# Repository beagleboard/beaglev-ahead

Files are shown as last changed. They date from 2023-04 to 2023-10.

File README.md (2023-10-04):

# BeagleV-Ahead

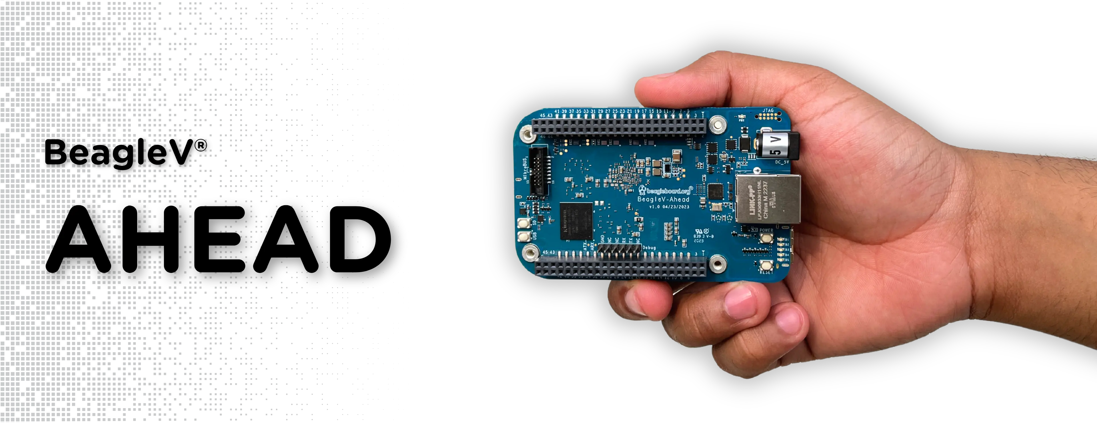
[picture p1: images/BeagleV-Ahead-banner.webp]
BeagleV Ahead banner


## Certified open source

<a href="https://certification.oshwa.org/us002535.html">
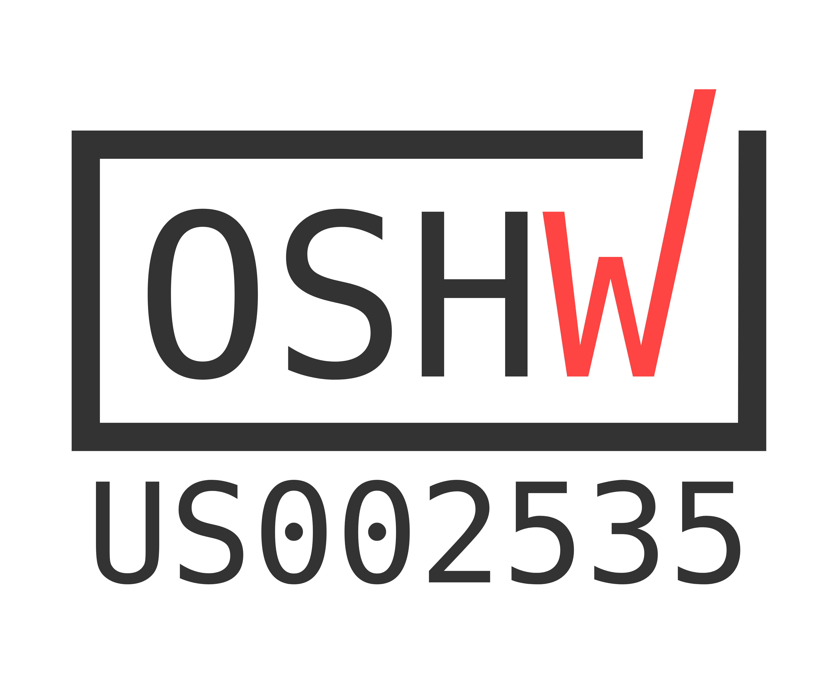
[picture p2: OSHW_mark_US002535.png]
   
</a>

## Links

* Terms and conditions: https://docs.beagleboard.org/latest/boards/terms-and-conditions.html
* Documentation: https://docs.beagleboard.org/latest/boards/beaglev/ahead
* Design: https://git.beagleboard.org/beaglev-ahead/beaglev-ahead
* Support: https://forum.beagleboard.org/tags/c/beaglev/15/ahead
* Repair: https://www.beagleboard.org/rma
* Purchase: https://beaglev-ahead.org

## Features

* T-Head TH1520 AI system-on-chip processor
   * Quad-core XuanTie C910 open-source RTL RISC-V (RV64GCV ISA) CPU @ 2GHz
     * 3 issue, 8 instruction, 9-12 stage pipeline
     * In-order fetch, out-of-order launch, out-of-order completion and in-order retirement
     * 64KB I-cache, 64KB D-cache per core
   * AI NPU with 4TOPS INT8 @ 1GHz
     * Support for TensorFlow, ONNX, Caffe
     * Feature extraction accelerator
   * Image signal processor
   * H.264/H.265/JPEG video encoder and decoder
   * 2D accelerator
   * 3D Vulkan/OpenCL/OpenGLES accelerator (IMG?)
   * C906-based (RV64IMA\[FD]C\[V] ISA) audio processor subsystem
* 4GB LPDDR4
* 16GB eMMC
* New Beagle form-factor open-source development board
   * ~2xSuperSpeed-USB type-A host (stacked)~
   * SuperSpeed USB type-C dual-role with power input (no power output)
   * Consider adding USB-to-serial/JTAG for the type-C device and move USB to host-only
   * Gigabit Ethernet with speed/connection indicators
   * HDMI type-A connector
   * TBD SDIO WiFi
   * uSD card cage
   * 2xCSI ribbon cable connectors
   * 1xDSI ribbon cable connector
   * 2x46-pin expansion headers with 4-pin HS-USB extension
   * 2x8-pin "mikroBus shuttle" ribbon-cable connector for audio and sensors
   * 3-pin TTL-level debug UART connector
   * Fan power connector (fan is optional)
   * 6x LEDs (1 power, 5 programmable)
   * 3x push-buttons (power, reset, boot/user)
   * 5V barrel jack
* BeagleBoard.org Debian Linux image
   * Tracking mainline u-boot/kernel with T-Head patches as needed
   * Package feeds for custom binaries for TensorFlow Lite, etc.
   * Familiar and flexible graphical user interface environment
   * Self-hosted Visual Studio Code IDE via web-browser
   * USB-based virtual network for "single-cable development"

# Requirements to begin
* Documentation needs to *start*
   * Reference schematic and PCB source files
      * Reference for DDR
      * Reference for PMIC and power design
   * Additional SoC details (Chinese language is good) - pointers to licensed IP is fine
      * Power consumption
   * Clear legal path to usage
      * Verify the IP in the SoC is licensed for use
      * Verify the IP *user* documentation can be public
      * Signed 3P agreement
   * Supplier part commitment
      * 10k parts for launch
      * ~~50k units per year~~
      * ~~fixed price and availability 5 years as long as 10k units per year~~
    * SDK source required to test board
      * Review Linux device tree
* Documentation needs to *launch*
   * Additional SoC details (Chinese language is good) - pointers to licensed IP is fine
      * Overview of SoC Memory Map
      * Boot process
      * Clocking and reset
      * Interrupts map or List
      * PLIC (Platform Level Interrupt Controller)
      * CLINT (Core-Local Interruptor)
      * L2 Cache Controller
      * DMA Controller
      * DDR interface
      * UART peripheral (including register map)
      * PWM peripheral (including register map)
      * I2C controller (including register map)
      * SPI controller (including register map)
      * GPIO controller (including register map)
      * Gigabit Ethernet MAC (including register map)
      * USB controller (including register map)
   * SDK source
      * Open source Linux kernel with reasonable SoC entitlement (or register-level detailed IP documentation)
      * V4L2 driver for video encoder/decoder
      * IMG 3D open source Mesa/Vulkan driver
      * libcamera and V4L2 driver for ISP and CSI video interace for common sensors (IMX219-based Pi camera)
      * DRM driver for the 2D image accelerator, display processing unit and DSI video interface
      * ALSA driver for audio interface

## DVT v0.2 testing

1. [Flash latest Ubuntu image](flashing.md)
2. [UART debug port access](debug.md)
3. [WiFi connection](WiFi.md)
4. [GPIO testing](GPIO.md)
5. [Bluetooth testing](Bluetooth.md)

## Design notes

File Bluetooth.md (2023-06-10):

# Setup Bluetooth

To connect to wifi we will be using `wpa_cli` tool, first we need to set the credentials for the wifi and then we will initialize the connection by reconfiguiring the wlan0 interface to use new credentials.
we use `brcm_patchram_plus` tool to setup bluetooth, first we need to trigger reset pin, then upload bluetooth fw.

```shell
#trigger reset pin
gpioset gpiochip2 28=0
gpioset gpiochip2 28=1

#upload fw
brcm_patchram_plus --enable_hci --no2bytes --tosleep 200000 --baudrate 3000000 --patchram /lib/firmware/BCM43013A0_001.001.006.1073.1102.hcd /dev/ttyS4 &
```

# Setup Bluetooth (with Debug)
```
#upload fw
brcm_patchram_plus -d --enable_hci --no2bytes --tosleep 200000 --baudrate 3000000 --patchram /lib/firmware/BCM43013A0_001.001.006.1073.1102.hcd /dev/ttyS4 &
```

## Check bluetooth interface

```
root@BeagleV:~# hciconfig 
hci0:	Type: Primary  Bus: UART
	BD Address: B8:13:32:EC:59:8B  ACL MTU: 1021:8  SCO MTU: 64:1
	DOWN 
	RX bytes:733 acl:0 sco:0 events:42 errors:0
	TX bytes:464 acl:0 sco:0 commands:42 errors:0
```

## Using bluetoothctl tool 

```
root@BeagleV:~# bluetoothctl 
Agent registered
[CHG] Controller B8:13:32:EC:59:8B Pairable: yes
[bluetooth]# scan on
Discovery started
[CHG] Controller B8:13:32:EC:59:8B Discovering: yes
[NEW] Device 40:97:1C:DF:8B:BD 40-97-1C-DF-8B-BD
[NEW] Device 43:07:E7:3F:85:84 43-07-E7-3F-85-84
[CHG] Device 43:07:E7:3F:85:84 RSSI: -91
[bluetooth]# quit

```

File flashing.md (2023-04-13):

# Flashing Ubuntu image

To start flashing the board download the latest image from the link below:

https://git.beagleboard.org/beaglev-ahead/xuantie-ubuntu/-/jobs

```
NOTE: New jobs are being executed regularly and it's recommended to download the most recent Ubuntu image by clicking the buttom marked in the image below.
```

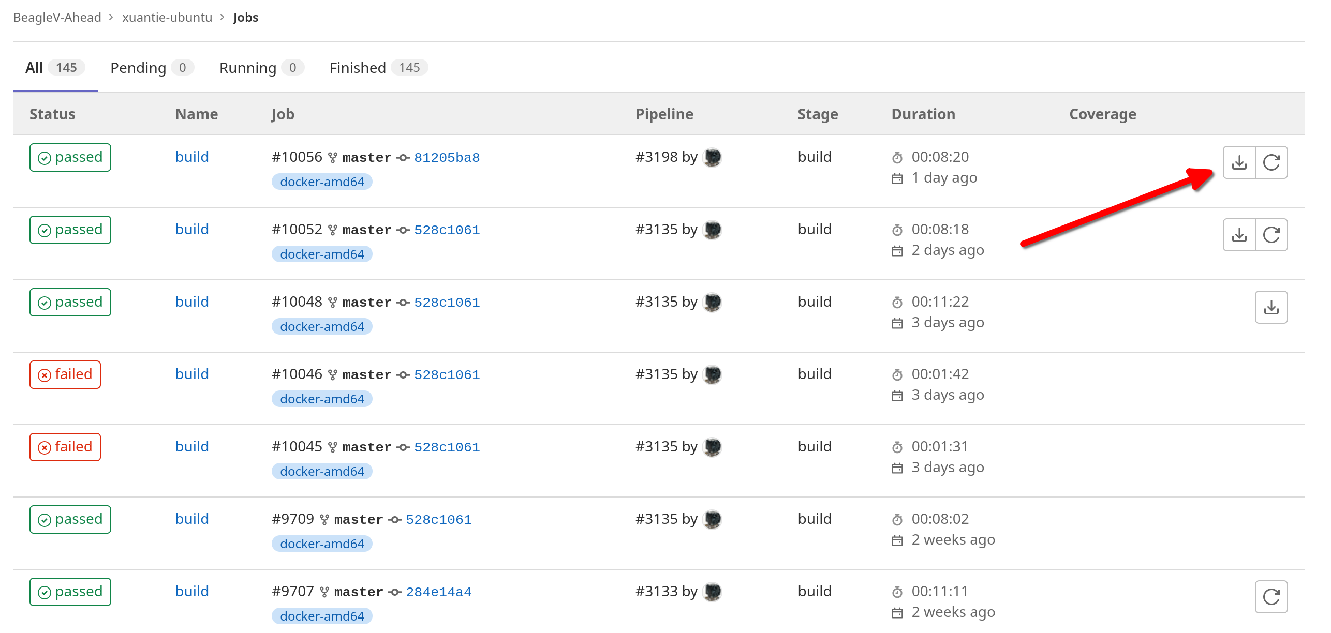
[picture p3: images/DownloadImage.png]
Download recent image


## Extract files
After downloading the `xuantie-ubuntu-<job-ID>.zip` using the link above, extract the zip file. The zip file has four files shown below:

    [lorforlinux@fedora deploy] $ ls 
        boot.ext4  fastboot_emmc.sh  root.ext4  u-boot-with-spl.bin

## Flash Board over USB

Press the USB button near SD card holder and then connect the board to PC with your custom USB3 (blue) cable provided with the BeagleV Ahead board. Now, Execute the command below, provide your password and the flashing will start.

    [lorforlinux@fedora deploy] $ sudo ./fastboot_emmc.sh 
    [sudo] password for lorforlinux:

```
NOTE: you may require to install adb & android-fastboot onto your system if not already available.
```

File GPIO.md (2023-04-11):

# GPIO

BeagleV Ahead has cape header pins similar to BeagleBone Black. You can check the documentation page below to know the pin connection to TH1520 SoC:

https://beaglev-ahead.beagleboard.io/docs/latest/boards/beaglev/ahead/connectros.html

To test the GPIO functionality of the pins you can follow steps below:

## Clone BeagleBoard-DeviceTrees

1. Access the shell with the help of [debug.md](debug.md)
2. Connect to WiFi usig [WiFi.md](WiFi.md)
3. Change directory to home using like below:

    ```
    beagle@BeagleV:~$ cd
    ```

4. Clone the repo using command below:

    ```
    beagle@BeagleV:~$ git clone https://git.beagleboard.org/beaglev-ahead/BeagleBoard-DeviceTrees.git
    ```

    Provide your credentials and the wait for cloning to complete.

## Teset gpio-leds with BONE-LED

Follow the steps below to test,

1. change the directory to home,

        ```
        beagle@BeagleV:~$ cd
        ```

2. If not already cloned clone the BeagleBoard-DeviceTrees repo,

    ```
    beagle@BeagleV:~$ git clone https://git.beagleboard.org/beaglev-ahead/BeagleBoard-DeviceTrees.git
    ```

3. Change directory to the repo,

    ```
    beagle@BeagleV:~$ cd BeagleBoard-DeviceTrees/
    ```

4. This step is not required for the first run but handy for further debugging,

    ```
    beagle@BeagleV:~$ make clean
    ```

5. make all the devicetree files and overlays for riscv

    ```
    beagle@BeagleV:~$ make all_riscv
    ```

6. Until uboot overlays support is functional you can use this command to update the base device tree file to include our overlay,

    ```
    beagle@BeagleV:~$ fdtoverlay \
    -i src/riscv/light-beagle.dtb \
    -o src/riscv/light-beagle.dtb \
    src/riscv/overlays/BONE-LED_P8_03.dtbo
    ```

7. Install all the files to your board,

    ```
    beagle@BeagleV:~$ sudo make install_riscv
    ```

8. Reboot your board,

    ```
    beagle@BeagleV:~$ sudo reboot
    ```

9. You should see LED blinking if connected to `P8_03`.

## Testing other pins

The overlay can be updated for other header pins and same steps can be used to test the pins as well. 

You'll have to change [this](https://git.beagleboard.org/beaglev-ahead/BeagleBoard-DeviceTrees/-/blob/v5.10.x-ti-unified/src/riscv/overlays/BONE-LED_P8_03.dts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) line according to the pin you want to use.

```
NOTE: It's okay if you don't change anything else like file name and other parts of the overlay to test other pins, you just have to change the reference according to the pin you want to test.
```

For `P8_03` the reference used is `bone_led_P8_03` for other pin like `P8_04` you need to change it to `bone_led_P8_04`. For example, testing `P8_22` will require you to make the change below:

```
&bone_led_P8_22 {
    status = "okay";
    // access: sys/class/leds/led_P8_22
    label = "led_P8_22";
    linux,default-trigger = "heartbeat";
    default-state = "on";
};
```

please note that this is only the portion of the code we need to edit, everything else can be exactly the same unless you really see the need to change it for yourself because it will not affect the testing procedure of the pin.

## Capes

Overlays for LOAD cape and Relay cape are also available to test under overlays folder,

https://git.beagleboard.org/beaglev-ahead/BeagleBoard-DeviceTrees/-/tree/v5.10.x-ti-unified/src/riscv/overlays

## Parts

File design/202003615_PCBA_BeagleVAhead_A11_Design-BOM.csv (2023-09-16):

标识 | 品牌 | MPN码 | 规格 | 插件位置 | 底数 | 数量 | 单位 | 承样状态 | 创建时间
202003615, PCBA; BeagleV-Ahead, A.11 (Design) |  |  |  |  |  |  |  |  | 2022/06/15 10:41 CST
301010000, SMD RES 0R-5%-1/16W;0402, A.2 (Design) | YAGEO | RC0402JR-070RL |  | R1 R6 R103 R124 R125 R126 R127 R128 R130 R200 R201 R202 R228 R229 R230 R233 R234 R242 R243 R486 R487 R651 R801 R802 R803 R804 R806 R807 R809 | 1 | 29 | PCS | 无需承样 | 2015/10/31 16:34 CST
301010048, SMD RES 30K-1%-1/16W;0402, A.1 (Design) | YAGEO | RC0402FR-0730KL |  | R116 R131 | 1 | 2 | PCS | 无需承样 | 2015/10/31 16:03 CST
301010081, SMD RES 200K-1%-1/16W;0402, A.1 (Design) | YAGEO | RC0402FR-07200KL |  | R136 R808 | 1 | 2 | PCS | 无需承样 | 2015/10/31 15:50 CST
301010359, SMD RES 0R-5%-1/8W;0805, A.1 (Design) | YAGEO | RC0805JR-070RL |  | R13 | 1 | 1 | PCS | 无需承样 | 2015/10/31 15:55 CST
301010410, SMD RES 1M-1%-1/4W;1206, A.1 (Design) | YAGEO | RC1206FR-071ML |  | R112 | 1 | 1 | PCS | 无需承样 | 2015/10/31 15:55 CST
301010442, SMD RES 100R-1%-1/16W;0402, A.1 (Design) | YAGEO | RC0402FR-07100RL |  | R7 | 1 | 1 | PCS | 无需承样 | 2015/10/31 15:47 CST
301010523, SMD RES 1K-±1%-1/20W;0201, A.1 (Design) | YAGEO | RC0201FR-071KL |  | R109 R110 R121 R123 R144 R185 R186 R187 R188 R189 R190 R191 R192 R193 R194 R195 R225 R232 | 1 | 18 | PCS | 无需承样 | 2015/10/31 16:25 CST
301010525, SMD RES 0R-±1%-1/20W;0201, A.1 (Design) | YAGEO | RC0201FR-070RL |  | R49 R52 R56 R61 R62 R74 R78 R106 R108 R156 R235 R236 R237 R238 R239 R240 R241 | 1 | 17 | PCS | 无需承样 | 2015/10/31 16:34 CST
301010526, SMD RES 10K-±1%-1/20W;0201, A.1 (Design) | YAGEO | RC0201FR-0710KL |  | R10 R15 R21 R40 R87 R91 R92 R93 R113 R117 R118 R129 R132 R133 R134 R137 R139 R141 R145 R146 R147 R148 R149 R158 R160 R162 R164 R166 R168 R169 R170 R171 R180 R203 R204 R205 R207 R209 R211 R213 R215 R217 R219 R221 R223 | 1 | 45 | PCS | 无需承样 | 2015/10/31 16:34 CST
301010671, SMD RES 2.7K-1%-1/16W;0402, A.2 (Design) | YAGEO | RC0402FR-072K7L |  | R143 | 1 | 1 | PCS | 未承样 | 2015/10/31 15:54 CST
301010675, SMD RES;33R-5%-1/20W;0201, A.1 (Design) | YAGEO | RC0201JR-0733RL |  | R5 R37 R53 R54 R55 R67 R68 R69 R70 R71 R72 R73 R75 R76 R77 R79 R83 R84 R85 R86 R88 R90 R150 | 1 | 23 | PCS | 未承样 | 2015/10/31 15:56 CST
301010676, SMD RES 1M-5%-1/20W;0201, A.3 (Design) | YAGEO | RC0201JR-071ML |  | R135 R138 R140 R142 R157 R159 R161 R163 R165 R167 R199 R206 R208 R210 R212 R214 R216 R218 R220 R222 R224 R226 | 1 | 22 | PCS | 无需承样 | 2015/10/31 16:02 CST
301010677, SMD RES;4.7K-5%-1/20W;0201, A.1 (Design) | YAGEO | RC0201JR-074K7L |  | R19 R22 R23 R28 R29 R30 R41 R42 R43 R45 R46 R47 R48 R57 R58 R59 R60 R63 R64 R65 R66 | 1 | 21 | PCS | 未承样 | 2015/10/31 16:02 CST
301010746, SMD RES 2.2K-1%-1/16W;0402, A.1 (Design) | YAGEO | RC0402FR-072K2L |  | R155 | 1 | 1 | PCS | 未承样 | 2015/10/31 16:54 CST
301010765, SMD RES 100K-±1%-1/20W;0201, A.1 (Design) | YAGEO | RC0201FR-07100KL |  | R44 R115 R119 R122 R172 R174 R181 R183 R184 R227 R673 R800 R810 R811 R813 R814 R815 R816 | 1 | 18 | PCS | 无需承样 | 2015/10/31 15:51 CST
301010817, SMD RES 1.62K-1%-1/20W;0201, A.3 (Design) | YAGEO | RC0201FR-071K62L |  | R94 R105 R114 R120 R755 | 1 | 5 | PCS | 无需承样 | 2015/10/31 17:01 CST
301010856, SMD RES 2.49K-1%-1/16W;0402, A.2 (Design) | YAGEO | RC0402FR-072K49L |  | R104 | 1 | 1 | PCS | 无需承样 | 2015/11/09 14:39 CST
301010860, SMD RES 124K-1%-1/16W;0402, A.2 (Design) | YAGEO | RC0402FR-07124KL |  | R102 | 1 | 1 | PCS | 无需承样 | 2015/11/09 14:42 CST
301011226, SMD RES 560K-1%-1/16W;0402, A.1 (Design) | YAGEO | RC0402FR-07560KL |  | R101 | 1 | 1 | PCS | 无需承样 | 2016/03/01 16:17 CST
301011318, SMD RES 240R-1%-1/20W;0201, A.1 (Design) | YAGEO | RC0201FR-07240RL |  | R3 R4 R8 R9 | 1 | 4 | PCS | 无需承样 | 2016/03/31 18:53 CST
301011323, SMD RES 120R-1%-1/20W;0201, A.1 (Design) | YAGEO | RC0201FR-07120RL |  | R11 R16 R35 | 1 | 3 | PCS | 无需承样 | 2016/03/31 19:01 CST
301011530, SMD RES 27R-1%-1/20W;0201, A.1 (Design) | YAGEO | RC0201FR-0727RL |  | R80 R81 R82 R89 R95 R96 | 1 | 6 | PCS | 无需承样 | 2016/08/12 14:10 CST
301012651, SMD RES 47K-1%-1/20W;0201, A.2 (Design) | Yageo | RC0201FR-0747KL |  | R20 R151 R152 R153 R154 | 1 | 5 | PCS | 无需承样 | 2019/05/10 11:09 CST
301013351, SMD RES 200R-1%-1/20W;0201, A.1 (Design) | YAGEO | RC0201FR-07200RL |  | R25 R751 R752 R753 R754 | 1 | 5 | PCS | 无需承样 | 2022/03/23 11:34 CST
302010002, SMD CAP Ceramic 47nF-25V-10%-X7R;0402, A.2 (Design) | YAGEO | CC0402KRX7R8BB473 |  | C643 | 1 | 1 | PCS | 无需承样 | 2015/10/31 16:48 CST
302010012, SMD CAP Ceramic 100pF-50V-5%-NPO;0402, A.2 (Design) | YAGEO | CC0402JRNPO9BN101 |  | C117 C121 | 1 | 2 | PCS | 无需承样 | 2015/10/31 15:45 CST
302010013, SMD CAP Ceramic 220pF-50V-5%-NPO;0402, A.2 (Design) | YAGEO | CC0402JRNPO9BN221 |  | C118 C120 | 1 | 2 | PCS | 无需承样 | 2015/10/31 15:45 CST
302010019, SMD CAP Ceramic 4.7uF-6.3V-20%-X5R;0402, A.2 (Design) | YAGEO | CC0402MRX5R5BB475 |  | C1 C2 C3 C5 C11 C13 C47 C54 C60 | 1 | 9 | PCS | 无需承样 | 2015/10/31 15:48 CST
302010232, SMD CAP Ceramic 470nF-10V-10%-X5R;0402, A.1 (Design) | YAGEO | CC0402KRX5R6BB474 |  | C642 C644 | 1 | 2 | PCS | 未承样 | 2015/10/31 15:51 CST
302010270, SMD CAP Ceramic;1uF-6.3V-±20%-X5R;0201, A.1 (Design) | YAGEO | CC0201MRX5R5BB105 |  | C21 C23 C25 C45 C46 C170 C171 C172 C173 C174 C179 C180 C257 C258 C259 C260 C261 C262 C268 C269 C270 C271 C272 C273 C274 C278 C281 C282 C283 C284 C288 C289 C290 C373 C374 C375 C457 C640 C1001 C1002 C1003 C1004 C1005 C1006 C1007 C1011 C1012 C1013 C1014 C1015 C1020 C1021 C1023 C1024 C1028 C1029 C1030 C1031 C1040 C1041 C1042 C1043 C1044 C1045 C1046 C1047 C1048 C1052 C1053 C1055 C1056 C1059 C1060 C1066 C1068 C1069 C1070 C1071 C1072 C1076 C1077 C1083 C1086 C1087 C1091 C1092 C1095 C1097 C1100 C1101 C1103 C1106 C1110 C1111 C1114 C1135 C1136 C1137 C1138 C1141 C1142 C1144 C1147 C1150 | 1 | 104 | PCS | 无需承样 | 2015/10/31 15:45 CST
302010271, SMD CAP Ceramic 100nF-10V-10%-X5R;0201, A.1 (Design) | YAGEO | CC0201KRX5R6BB104 |  | C4 C6 C12 C14 C20 C22 C24 C26 C27 C28 C29 C33 C37 C38 C39 C40 C41 C42 C44 C48 C49 C50 C51 C52 C53 C55 C56 C57 C58 C59 C61 C62 C65 C66 C67 C68 C72 C74 C75 C76 C77 C78 C79 C80 C81 C82 C83 C84 C85 C86 C87 C88 C89 C90 C91 C92 C93 C94 C97 C98 C99 C100 C101 C102 C103 C104 C105 C106 C107 C108 C109 C110 C111 C112 C113 C114 C115 C116 C176 C177 C181 C275 C276 C277 C285 C286 C1008 C1009 C1026 C1027 C1051 C1057 C1062 C1073 C1074 C1084 C1093 C1098 C1109 C1140 | 1 | 100 | PCS | 无需承样 | 2015/10/31 15:46 CST
302010273, SMD CAP Ceramic;22pF-50V-5%-NPO;0201, A.1 (Design) | YAGEO | CC0201JRNPO9BN220 |  | C9 C15 C31 C32 C333 C336 C634 C639 | 1 | 8 | PCS | 无需承样 | 2015/10/31 15:47 CST
302010394, SMD CAP Ceramic 1nF-50V-5%-X7R;0402, A.1 (Design) | YAGEO | CC0402JRX7R9BB102 |  | C34 C119 C122 | 1 | 3 | PCS | 未承样 | 2015/10/31 15:52 CST
302010406, SMD CAP Ceramic 18pF-50V-5%-NPO;0201, A.1 (Design) | Murata | GRM0335C1H180JA01D |  | C16 C337 C338 | 1 | 3 | PCS | 无需承样 | 2015/10/31 16:24 CST
302010411, SMD CAP Ceramic 22uF-10V-20%-X5R;0603, A.1 (Design) | YAGEO | CC0603MRX5R6BB226 |  | C10 C123 C169 C267 C600 C603 C604 C605 C607 C609 C610 C632 C633 C1000 C1010 C1119 C1120 C1129 C1130 | 1 | 19 | PCS | 无需承样 | 2015/10/31 16:47 CST
302010739, SMD CAP Ceramic 47uF-6.3V-20%-X5R;0603, A.1 (Design) | Murata | GRM188R60J476ME15D |  | C73 C601 C602 C606 C612 C620 C628 C629 C630 C673 C687 C1037 C1038 C1039 | 1 | 14 | PCS | 无需承样 | 2016/04/11 11:39 CST
302011831, SMD CAP Ceramic 10nF-6.3V-10%-X5R;0201, A.2 (Design) | Yageo | CC0201KRX5R5BB103 |  | C458 | 1 | 1 | PCS | 无需承样 | 2019/05/09 15:14 CST
302011962, SMD CAP Ceramic 1nF-2kV-10%-X7R;1206, A.3 (Design) | YAGEO | CC1206KKX7RDBB102 |  | C30 | 1 | 1 | PCS | 无需承样 | 2019/06/12 19:09 CST
302012841, SMD CAP Ceramic;220nF-10V-10%-X5R;0201, A.2 (Design) | YAGEO | CC0201KRX5R6BB224 |  | C641 | 1 | 1 | PCS | 无需承样 | 2021/02/18 16:15 CST
302013119, SMD CAP Ceramic 1uF-4V-20%-X7T;0204, A.2 (Design) | Murata | LLL152D70G105ME01D |  | C1122 C1123 C1124 C1125 C1127 C1128 | 1 | 6 | PCS | 无需承样 | 2022/07/19 16:07 CST
302013249, SMD CAP Ceramic 1uF-10V-10%-X5R;0402, A.1 (Design) | SAMSUNG | CL05A105KP5NNNC |  | C63 C64 C70 C71 C95 C96 C638 | 1 | 7 | PCS | 无需承样 | 2023/03/29 14:09 CST
302013250, SMD CAP Ceramic 10uF-6.3V-20%-X5R;0402, A.1 (Design) | SAMSUNG | CL05A106MQ5NUNC |  | C178 C287 C1034 C1035 C1036 C1067 C1075 C1085 | 1 | 8 | PCS | 无需承样 | 2023/03/29 14:13 CST
302013252, SMD CAP Ceramic 10uF-10V-10%-X5R;0603, A.1 (Design) | SAMSUNG | CL10A106KP8NNNC |  | C8 C19 C36 C43 | 1 | 4 | PCS | 无需承样 | 2023/03/29 14:14 CST
302013264, SMD CAP Ceramic 100uF-10V-20%-X5R;1210, A.1 (Design) | SAMSUNG | CL32A107MPVNNNE |  | C69 C631 | 1 | 2 | PCS | 无需承样 | 2023/03/29 14:16 CST
302013266, SMD CAP Ceramic 2.2uF-10V-10%-X5R;0402, A.1 (Design) | SAMSUNG | CL05A225KP5NSNC |  | C608 C611 C614 C615 C616 C617 C618 C619 C622 C623 C624 C625 C626 C627 | 1 | 14 | PCS | 无需承样 | 2023/03/29 14:16 CST
303010172, SMD Innductor 0.47uH-20%;L2.0*W1.6*H1.0mm, A.1 (Design) | Sunlord | WPN201610MR47MT |  | L2 | 1 | 1 | PCS | 无需承样 | 2015/10/31 15:46 CST
303011382, SMD Inductor 1uH-20%-3.1A;L2.0*W1.6*H1.0mm, A.3 (Design) | Sunlord | WPN201610U1R0MTY01 |  | L36 L37 L38 L39 L40 L43 | 1 | 6 | PCS | 无需承样 | 2020/03/12 14:51 CST
303011790, SMD Inductor;4.7uH-20%-1.5A-2.5*2.0*1.2mm, A.2 (Design) | CODACA | CSTB252012H-4R7M |  | L1 | 1 | 1 | PCS | 无需承样 | 2022/07/19 16:14 CST
303011791, SMD Inductor 2.2uH-20%-2A;L2.0*W1.6*H1.0mm, A.2 (Design) | CODACA | CSTB201610H-2R2M |  | L3 | 1 | 1 | PCS | 无需承样 | 2022/07/19 16:17 CST
303011792, SMD Inductor;0.16uH-20%-5A-2.5*2.0*1.0mm, A.2 (Design) | Sunlord | WPN252010UR16MT |  | L41 L42 | 1 | 2 | PCS | 无需承样 | 2022/07/19 16:28 CST
303030024, SMD Ferrite Bead;120R-2A;0603, A.4 (Design) | Murata | BLM18PG121SN1D |  | FB1 FB16 | 1 | 2 | PCS | 无需承样 | 2015/10/31 16:53 CST
303030040, SMD Ferrite Bead 120R-1.3A;0402, A.2 (Design) | Murata | BLM15PD121SN1D |  | FB2 FB3 FB13 FB15 | 1 | 4 | PCS | 无需承样 | 2015/11/13 16:49 CST
303030859, SMD Ferrite Bead 600R 250mA;0201, A.2 (Design) | Murata | BLM03AX601SN1B |  | FB5 FB6 FB7 FB8 FB9 FB10 FB11 FB12 | 1 | 8 | PCS | 无需承样 | 2022/07/19 16:04 CST
304020024, SMD Diode Schottky 30V-1A;DO-214AC, A.2 (Design) | Diodes | B130L-13-F |  | D24 D28 | 1 | 2 | PCS | 未承样 | 2015/10/31 15:45 CST
304020782, SMD Diode Schottky 30V-200mA;SOD-523, A.3 (Design) | ON | RB520S30T1G |  | D3 D9 D13 D32 D35 D38 | 1 | 6 | PCS | 无需承样 | 2020/04/01 17:24 CST
304050002, SMD Diode TVS 5V-600W;DO-214AA, A.2 (Design) | ST | SMBJ5.0CA-TR |  | D22 | 1 | 1 | PCS | 未承样 | 2015/10/31 16:52 CST
304050579, SMD Diode TVS 24VWM 29.5V;SMB, A.3 (Design) | Littelfuse | SMBJ24CA |  | D25 | 1 | 1 | PCS | 无需承样 | 2018/07/11 16:16 CST
304050798, SMD TVS DIODE 3.6V-6.4V-1pF;X1SON(2), A.3 (Design) | TI | TPD1E1B04DPYR |  | D14 D15 D16 D17 D18 D26 D27 | 1 | 7 | PCS | 无需承样 | 2020/01/10 11:05 CST
304060074, SMD Diode ESD 0.05pF;0402, A.3 (Design) | SEMITEL | ESDPSA0402V05 |  | D6 D7 D8 D10 D11 D19 D20 D21 D36 D37 | 1 | 10 | PCS | 无需承样 | 2015/12/28 10:56 CST
304060294, SMD Diode Array ESD;4 Channel,6 Gbps,5.5V;USON-10, A.4 (Design) | TI | TPD4E05U06DQAR | Air=±15KV；Contact=±12KV | D1 D2 D4 D5 | 1 | 4 | PCS | 无需承样 | 2020/05/14 18:47 CST
304060395, SMD Diode Array ESD;4 Channel,0.25pF,3.6V,10Gbps;USON-10, A.2 (Design) | TI | TPD4E02B04DQAR | Air=±15KV；Contact=±12KV | D12 | 1 | 1 | PCS | 无需承样 | 2022/03/21 15:05 CST
304090043, SMD LED Clear-Green;LED-0603, C.2 (Design) | Everlight | 19-217/G7C-AN1P2/6T | (正贴) | LED6 | 1 | 1 | PCS | 无需承样 | 2015/10/31 16:52 CST
304090045, SMD LED Clear-Blue;0603, A.3 (Design) | Everlight | 19-217/BHC-ZL1M2RY/6T |  | LED1 LED2 LED3 LED4 LED5 | 1 | 5 | PCS | 无需承样 | 2015/10/31 15:45 CST
305010033, SMD Transistor NPN 50V-500mA;SOT-323, A.2 (Design) | 长电 | BC817W |  | Q11 | 1 | 1 | PCS | 已承样 | 2015/10/31 15:48 CST
305030084, SMD MOSFET P-CH 20V-2.1A;SOT-323, A.1 (Design) | 长电 | CJ2101 |  | Q4 | 1 | 1 | PCS | 未承样 | 2015/10/31 15:51 CST
305030659, SMD MOSFET N-CH 20V -630MA ；SOT-523, A.2 (Design) | Diodes | DMG1012T-7 |  | Q3 Q7 Q8 Q9 Q10 Q12 Q13 Q14 Q16 Q17 Q18 Q19 Q20 Q26 Q27 | 1 | 15 | PCS | 无需承样 | 2017/09/28 10:33 CST
305031179, SMD MOSFET P-CH 30V-12A;HSMT8, A.2 (Design) | Rohm | RQ3E120ATTB |  | Q15 Q21 Q22 | 1 | 3 | PCS | 无需承样 | 2020/05/07 11:09 CST
305050191, SMD Transistor Array 2PNP 45V-0.1A;SOT36, A.2 (Design) | Diodes Incorporated | BCM857BS-7-F |  | Q23 Q24 | 1 | 2 | PCS | 无需承样 | 2019/05/10 09:59 CST
306010138, SMD Crystal 32.768KHz-12.5pF-20ppm-2P-3.2*1.5*0.9mm, A.3 (Design) | EPSON | FC-135 32.7680KA-A3 | (指定品牌) | Y1 Y8 | 1 | 2 | PCS | 无需承样 | 2015/10/31 17:02 CST
306011192, SMD Crystal 25MHz-18pF-20ppm;4P-SMD-L3.2*W2.5*H0.8mm, A.2 (Design) | Interquip | 5YAA25000182TF40Q3 |  | Y3 | 1 | 1 | PCS | 无需承样 | 2021/04/28 14:50 CST
306011309, SMD Crystal 24MHz-12pF-20ppm-60R;4P-SMD-L3.2*W2.5*H0.8mm, A.2 (Design) | Interquip | 5YAA24000122TF60Q3 |  | Y2 | 1 | 1 | PCS | 无需承样 | 2022/07/19 16:59 CST
306011310, SMD Crystal 37.4MHz-16pF-10ppm-40R;4P-SMD-L3.2*W2.5*H0.8mm, A.2 (Design) | Interquip | 5YAA37400161TF40Q3 |  | Y4 | 1 | 1 | PCS | 无需承样 | 2022/07/19 17:01 CST
306020621, SMD Oscillator;32.768KHz-3.3V-30ppm;SMD-2520-4P-L2.5*W2.0*H0.95mm, A.2 (Design) | Interquip | 1651-L3273-BTBQYA |  | OSC1 | 1 | 1 | PCS | 无需承样 | 2020/06/01 17:10 CST
306050630, SMD Feed Through Capacitor(Filters);4.3uF-20%-DC 2.5V-2A-30mOhm;0402, A.2 (Design) | Murata | NFM15PC435R0E3D |  | C1115 C1116 C1117 C1118 C1133 C1134 | 1 | 6 | PCS | 无需承样 | 2022/07/19 15:49 CST
306050631, SMD Feed Through Capacitor(Filters);22nF-20%-DC 10V-1A-40mOhm;0402, A.2 (Design) | Murata | NFM15CC223C1A3D |  | C1151 | 1 | 1 | PCS | 无需承样 | 2022/07/19 15:54 CST
310011577, SMD IC MCU;Quad-core RISC-V 2GHz;FCCSP-921(15*15), A.2 (Design) | T-HEAD | TH1520-C0X-XXXX7 |  | U1 | 1 | 1 | PCS | 无需承样 | 2022/07/19 16:32 CST
310030161, SMD IC PMIC;DFN(2*2)-8, B.2 (Design) | ETA | ETA3410D2I-T |  | U6 | 1 | 1 | PCS | 已承样 | 2015/10/31 16:48 CST
310031388, SMD IC PMIC; IC VREF SHUNT ADJ;SOT23-3, A.3 (Design) | TI | ATL431AIDBZR |  | U10 | 1 | 1 | PCS | 无需承样 | 2018/03/09 10:55 CST
310031691, SMD IC PMIC;LDO-1.8V-600mA;SOT23-5, A.2 (Design) | Diodes | AP2112K-1.8TRG1 |  | U21 | 1 | 1 | PCS | 无需承样 | 2019/05/29 10:35 CST
310032613, SMD IC PMIC;BGA-100(8*8), A.2 (Design) | Dialog | DA9063-ABHO2(T-HEAD烧录固件) |  | U81 | 1 | 1 | PCS | 无需承样 | 2022/07/19 16:52 CST
310032614, SMD IC PMIC;DCDC Buck-ADJ 2.2-V to 5.5-V Input 10-A;24WLCSP, A.2 (Design) | Dialog | DA9121-A2V72(T-HEAD提供） |  | U83 | 1 | 1 | PCS | 无需承样 | 2022/07/19 16:56 CST
310051370, SMD IC Logic;4-Bit Bidirectional Voltage-Level Translator;DSBGA-12, A.2 (Design) | Union Semiconductor | UM3304 |  | U7 U11 U12 U13 U14 U15 U16 U18 U19 U23 U24 U25 U26 U27 U28 U30 U31 | 1 | 17 | PCS | 无需承样 | 2022/07/19 16:51 CST
310051371, SMD IC Logic;4-Bit Bidirectional Voltage-Level Translator;DSBGA-12, A.2 (Design) | Union Semiconductor | UM3204H |  | U17 U22 U29 | 1 | 3 | PCS | 无需承样 | 2022/07/19 16:54 CST
310091085, SMD IC Memory;16GB eMMC 5.1;VFBGA-153, A.2 (Design) | Kingston | EMMC16G-TB29-PZ90 |  | U3 | 1 | 1 | PCS | 无需承样 | 2020/06/01 16:06 CST
310091347, SMD IC Memory;32Kb-IIC Serial EEPROM;SOT23-5, A.2 (Design) | FMD | FT24C32A-ELRT |  | U20 | 1 | 1 | PCS | 无需承样 | 2022/03/02 14:13 CST
310091405, SMD IC Memory;LPDDR4X 2GB(16bits x 2 channels) 2133MHz 4266Mbps;WFBGA-200 (10X15), A.2 (Design) | Samsung | K4U6E3S4AA-MGCR |  | UD1 UD2 | 1 | 2 | PCS | 无需承样 | 2022/07/19 16:58 CST
310990024, SMD Precision Load Switch with Adjustable Curren IC;DFN22-6, A.1 (Design) | ETA | ETA6020D2G-T/U |  | U5 U8 U9 | 1 | 3 | PCS | 已承样 | 2015/10/31 15:54 CST
310991199, SMD IC 1000Base-T Ethernet Transceiver;QFN40, A.2 (Design) | Realtek | RTL8211F-VD-CG |  | U4 | 1 | 1 | PCS | 无需承样 | 2022/07/19 16:44 CST
311020518, SMD Top Button 1.57N;4P-L4.6*W3.2*H2.5mm, A.3 (Design) | ALPS | SKRPABE010 |  | SW1 SW2 SW3 SW4 | 1 | 4 | PCS | 无需承样 | 2017/11/02 14:26 CST
317060602, SMD WIFI Module ;1T1R 802.11 a/ b/g/n Wi-Fi + BT 5.2;SDIO,UART/PCM;12*12*1.7mm, A.2 (Design) | Ampak | AP6203BM |  | U2 | 1 | 1 | PCS | 无需承样 | 2022/07/19 16:37 CST
319015460, PCB; BeagleV-Ahead_v1.0-蓝油白字-10层, A.3 (Design) |  |  | 96.5*60.7*1.6mm-化学沉金-EM-390 |  | 1 | 1 | PCS | 无需承样 | 2023/04/21 16:27 CST
320010901, SMD HDMI Type D Right Angle;SMT+DIP-19P, A.3 (Design) | FCI | 10118241-001RLF |  | J1 | 1 | 1 | PCS | 无需承样 | 2020/02/12 17:20 CST
320011259, SMD+DIP Micro USB 3.0 TYPE B;10P+7, A.2 (Design) | MTCONN | UBF30-0101 |  | J6 | 1 | 1 | PCS | 无需承样 | 2022/07/19 16:11 CST
320020078, DIP Black Male Header VERT;1*6P-2.54-2.5-11.5/3.0mm, B.2 (Design) | 思拓展 | ST-PH-254-0087-1*6P-6T | PH2.54 H2.5 180度 L11.5 PC3.0 PA6.0 镀金0.8U PA6T料 | J10 | 1 | 1 | PCS | 已承样 | 2015/10/31 16:29 CST
320031344, SMD+DIP Black Female Header;2*23P-2.54*8.5-3.0mm, A.5 (Design) | 思拓展 | ST-FH-254-0182-2*23 | FH:2.54 H:8.5 PC:3.0/7.1MM 第1.2.22.23列为直插 第3至21列为贴片 2*23Pin | P8 P9 | 1 | 2 | PCS | 无需承样 | 2021/07/08 16:45 CST
320060764, SMD FPC CONN;22P-0.5mm-90D-Bottom Contact-L15.40*W5.25*H2.00mm, A.3 (Design) | 百斯特 | 0.5K-DX-22PWB |  | J3 J4 J5 | 1 | 3 | PCS | 无需承样 | 2021/07/08 16:48 CST
320090416, SMD SD Card Holder;Reverse-Bottom,8P-14.3*16mm, A.3 (Design) | YU LIANG(宇亮) | YL004-030-001 |  | J15 | 1 | 1 | PCS | 无需承样 | 2021/02/20 17:10 CST
320111077, SMD U-FL Female CONN-Gold;3P-L2.6*W2.6*H1.25mm, A.5 (Design) | HRS | U.FL-R-SMT-1 |  | J2 | 1 | 1 | PCS | 无需承样 | 2018/08/16 13:43 CST
320120003, DIP DC Power Jack W/P-2.0-Black;3P-L14.2*W9.0*H11.0mm-90D, A.1 (Design) | 百斯特 | DC-005 |  | J8 | 1 | 1 | PCS | 未承样 | 2015/10/31 16:21 CST
320140517, DIP RJ45;1000M,Integrated Magnetics,G/O/Y 3 LEDs,Right Angle;16P-21.25*15.93*13.3mm, A.2 (Design) | LINK-PP | LPJG0933H11NL |  | J14 | 1 | 1 | PCS | 无需承样 | 2022/03/01 15:05 CST
320150353, SMD Box Header with 3 slots;2*8P-1.27mm, A.3 (Design) | 思拓展 | ST-BF-127-2*8A-C | BH:1.27 H:4.9 SMT PC:5.6 2x8PIN 黄铜镀金0.8U PA6T料 两端开口 | J7 | 1 | 1 | PCS | 无需承样 | 2021/09/23 11:30 CST
326050947, SMD Stud; M3螺柱, 反向垫片, D6*1MM+D4.2*6.6MM, 铁料, 表面电镀锡（编带包装, 贴麦拉）, A.2 (Design) | Sinhoo | SMSR3066MTJ | 雄和远景, M3*6*6.6+1 | MH1 MH2 MH3 MH4 | 1 | 4 | PCS | 无需承样 | 2021/11/22 10:00 CST
327131816, 空白标签;5000pcs卷-5列-耐高温300度-7*14mm, C.1 (Design) |  |  |  |  | 1 | 1 | PCS | 无需承样 | 2018/08/13 14:42 CST
327132464, DC贴纸;5V-富洲25#油胶强粘哑银龙+过哑胶-12*8mm, A.2 (Design) |  |  |  | Label 1 | 1 | 1 | PCS | 无需承样 | 2020/09/23 09:11 CST

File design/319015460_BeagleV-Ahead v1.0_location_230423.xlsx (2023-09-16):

Component Report
E:/huangwei/complete/202304/BEAGLEV-AHEAD/BEAGLEV-AHEAD V10.brd
Sun Apr 23 11:19:02 2023
Total Components: 821
REFDES | COMP_DEVICE_TYPE | COMP_VALUE | COMP_TOL | COMP_PACKAGE | SYM_X | SYM_Y | SYM_ROTATE | SYM_MIRROR
C1 | CC_C0402_DISCRETE_4.7UF | 4.7uF |  | C0402 | 2439.5 | 3353.22 | 0 | NO
C2 | CC_C0402_DISCRETE_4.7UF | 4.7uF |  | C0402 | 1915 | 3455 | 180 | YES
C3 | CC_C0402_DISCRETE_4.7UF | 4.7uF |  | C0402 | 2206 | 2817.2 | 180 | YES
C4 | CC_C0201_DISCRETE_100NF | 100nF |  | C0201 | 1910 | 3425 | 180 | YES
C5 | CC_C0402_DISCRETE_4.7UF | 4.7uF |  | C0402 | 2265 | 3375 | 270 | YES
C6 | CC_C0201_DISCRETE_100NF | 100nF |  | C0201 | 2295 | 3370 | 270 | YES
C7 | CC_C0201_DISCRETE_22PF | 22pF |  | C0201 | 2615 | 3490.45 | 0 | NO
C8 | CC_C0603_DISCRETE_10UF | 10uF |  | C0603 | 1923.2 | 2509.79 | 180 | NO
C9 | CC_C0201_DISCRETE_22PF | 22pF |  | C0201 | 1798.7 | 2205.56 | 180 | NO
C10 | CC_C0603_DISCRETE_22UF | 22uF |  | C0603 | 1924.7 | 2298.12 | 0 | NO
C11 | CC_C0402_DISCRETE_4.7UF | 4.7uF |  | C0402 | 2120.5 | 2926.78 | 180 | NO
C12 | CC_C0201_DISCRETE_100NF | 100nF |  | C0201 | 2123.5 | 2963.45 | 180 | NO
C13 | CC_C0402_DISCRETE_4.7UF | 4.7uF |  | C0402 | 2117.42 | 3016.78 | 180 | NO
C14 | CC_C0201_DISCRETE_100NF | 100nF |  | C0201 | 2430.5 | 3617.75 | 0 | NO
C15 | CC_C0201_DISCRETE_22PF | 22pF |  | C0201 | 1732.17 | 3407.2 | 90 | NO
C16 | CC_C0201_DISCRETE_18PF | 18pF |  | C0201 | 1660.3 | 3398 | 180 | NO
C17 | CC_C0201_DISCRETE_1PF | 1pF |  | C0201 | 1763.32 | 3746.2 | 180 | NO
C18 | CC_C0201_DISCRETE_1PF | 1pF |  | C0201 | 1763.32 | 3678.93 | 180 | NO
C19 | CC_C0603_DISCRETE_10UF | 10uF |  | C0603 | 2896.34 | 3787.3 | 270 | NO
C20 | CC_C0201_DISCRETE_100NF | 100nF |  | C0201 | 2125 | 2985 | 180 | NO
C21 | CC_C0201_DISCRETE_1UF | 1uF |  | C0201 | 1981.55 | 3108.5 | 270 | NO
C22 | CC_C0201_DISCRETE_100NF | 100nF |  | C0201 | 1963.45 | 2948.5 | 90 | NO
C23 | CC_C0201_DISCRETE_1UF | 1uF |  | C0201 | 2189.4 | 3128.5 | 180 | YES
C24 | CC_C0201_DISCRETE_100NF | 100nF |  | C0201 | 2189.4 | 3150.4 | 180 | YES
C25 | CC_C0201_DISCRETE_1UF | 1uF |  | C0201 | 1951.5 | 3091.55 | 0 | NO
C26 | CC_C0201_DISCRETE_100NF | 100nF |  | C0201 | 1951.5 | 2986.55 | 0 | NO
C27 | CC_C0201_DISCRETE_100NF | 100nF |  | C0201 | 1993.45 | 2945.5 | 90 | NO
C28 | CC_C0201_DISCRETE_100NF | 100nF |  | C0201 | 1951.5 | 3066.55 | 0 | NO
C29 | CC_C0201_DISCRETE_100NF | 100nF |  | C0201 | 2204.2 | 2783.4 | 180 | YES
C30 | CC_C1206_DISCRETE_1NF | 1nF |  | C1206 | 1163 | 3484.89 | 180 | NO
C31 | CC_C0201_DISCRETE_22PF | 22pF |  | C0201 | 1895 | 2810.99 | 0 | YES
C32 | CC_C0201_DISCRETE_22PF | 22pF |  | C0201 | 2106.75 | 2804.93 | 270 | YES
C33 | CC_C0201_DISCRETE_100NF | 100nF |  | C0201 | 2843.4 | 3874.05 | 180 | NO
C34 | CC_C0402_DISCRETE_1NF | 1nF |  | C0402 | 2751.7 | 3144.89 | 0 | NO
C35 | CC_C0201_DISCRETE_22PF | 22pF |  | C0201 | 2323.94 | 2975 | 0 | YES
C36 | CC_C0603_DISCRETE_10UF | 10uF |  | C0603 | 4156.1 | 3827.05 | 180 | NO
C37 | CC_C0201_DISCRETE_100NF | 100nF |  | C0201 | 4162.3 | 3874.95 | 180 | NO
C38 | CC_C0201_DISCRETE_100NF | 100nF |  | C0201 | 3137.23 | 3129.59 | 270 | YES
C39 | CC_C0201_DISCRETE_100NF | 100nF |  | C0201 | 3275.01 | 3160.27 | 90 | YES
C40 | CC_C0201_DISCRETE_100NF | 100nF |  | C0201 | 3122.7 | 3206.89 | 90 | YES
C41 | CC_C0201_DISCRETE_100NF | 100nF |  | C0201 | 3308.6 | 3204.8 | 270 | YES
C42 | CC_C0201_DISCRETE_100NF | 100nF |  | C0201 | 3270.41 | 3061.91 | 0 | YES
C43 | CC_C0603_DISCRETE_10UF | 10uF |  | C0603 | 3587 | 3865.11 | 0 | NO
C44 | CC_C0201_DISCRETE_100NF | 100nF |  | C0201 | 3230.41 | 3058.58 | 0 | YES
C45 | CC_C0201_DISCRETE_1UF | 1uF |  | C0201 | 4486.5 | 2578.45 | 0 | YES
C46 | CC_C0201_DISCRETE_1UF | 1uF |  | C0201 | 4437.5 | 2578.45 | 180 | YES
C47 | CC_C0402_DISCRETE_4.7UF | 4.7uF |  | C0402 | 4331 | 2600.5 | 270 | YES
C48 | CC_C0201_DISCRETE_100NF | 100nF |  | C0201 | 4299.1 | 2603.1 | 270 | YES
C49 | CC_C0201_DISCRETE_100NF | 100nF |  | C0201 | 4274.1 | 2603.1 | 270 | YES
C50 | CC_C0201_DISCRETE_100NF | 100nF |  | C0201 | 3910 | 2580 | 90 | NO
C51 | CC_C0201_DISCRETE_100NF | 100nF |  | C0201 | 3965.1 | 2682.9 | 180 | NO
C52 | CC_C0201_DISCRETE_100NF | 100nF |  | C0201 | 3930 | 2580 | 90 | NO
C53 | CC_C0201_DISCRETE_100NF | 100nF |  | C0201 | 3970 | 2620 | 180 | NO
C54 | CC_C0402_DISCRETE_4.7UF | 4.7uF |  | C0402 | 3880 | 2575 | 90 | NO
C55 | CC_C0201_DISCRETE_100NF | 100nF |  | C0201 | 4437.5 | 2553.45 | 180 | YES
C56 | CC_C0201_DISCRETE_100NF | 100nF |  | C0201 | 3870 | 2675 | 270 | NO
C57 | CC_C0201_DISCRETE_100NF | 100nF |  | C0201 | 3890 | 2755 | 90 | NO
C58 | CC_C0201_DISCRETE_100NF | 100nF |  | C0201 | 3865 | 2755 | 90 | NO
C59 | CC_C0201_DISCRETE_100NF | 100nF |  | C0201 | 3915 | 2755 | 90 | NO
C60 | CC_C0402_DISCRETE_4.7UF | 4.7uF |  | C0402 | 3835 | 2770 | 90 | NO
C61 | CC_C0201_DISCRETE_100NF | 100nF |  | C0201 | 3785 | 2515 | 180 | NO
C62 | CC_C0201_DISCRETE_100NF | 100nF |  | C0201 | 3516.47 | 3868.66 | 270 | NO
C63 | CC_C0402_DISCRETE_1UF | 1uF |  | C0402 | 1685.2 | 2422.08 | 0 | YES
C64 | CC_C0402_DISCRETE_1UF | 1uF |  | C0402 | 4634.52 | 2783 | 90 | YES
C65 | CC_C0201_DISCRETE_100NF | 100nF |  | C0201 | 4602.1 | 2783.66 | 90 | YES
C66 | CC_C0201_DISCRETE_100NF | 100nF |  | C0201 | 1511.2 | 2183.11 | 180 | NO
C67 | CC_C0201_DISCRETE_100NF | 100nF |  | C0201 | 1642.5 | 3458.45 | 180 | YES
C68 | CC_C0201_DISCRETE_100NF | 100nF |  | C0201 | 1511.13 | 2161.85 | 180 | NO
C69 | CC_C1210_DISCRETE_100UF | 100uF |  | C1210 | 1605.15 | 2373.3 | 270 | NO
C70 | CC_C0402_DISCRETE_1UF | 1uF |  | C0402 | 4635.12 | 2691.5 | 270 | YES
C71 | CC_C0402_DISCRETE_1UF | 1uF |  | C0402 | 1594.2 | 2420.65 | 180 | YES
C72 | CC_C0201_DISCRETE_100NF | 100nF |  | C0201 | 1594.2 | 2388.08 | 180 | YES
C73 | CC_C0603_47UF | 47uF |  | C0603 | 1920.2 | 3502.5 | 180 | YES
C74 | CC_C0201_DISCRETE_100NF | 100nF |  | C0201 | 3743.32 | 2005.99 | 0 | NO
C75 | CC_C0201_DISCRETE_100NF | 100nF |  | C0201 | 3743.32 | 2025.99 | 0 | NO
C76 | CC_C0201_DISCRETE_100NF | 100nF |  | C0201 | 4056.32 | 2006.99 | 0 | NO
C77 | CC_C0201_DISCRETE_100NF | 100nF |  | C0201 | 4056.32 | 2026.99 | 0 | NO
C78 | CC_C0201_DISCRETE_100NF | 100nF |  | C0201 | 3569.32 | 2008.99 | 0 | NO
C79 | CC_C0201_DISCRETE_100NF | 100nF |  | C0201 | 3569.32 | 2028.99 | 0 | NO
C80 | CC_C0201_DISCRETE_100NF | 100nF |  | C0201 | 3227.32 | 2005.99 | 0 | NO
C81 | CC_C0201_DISCRETE_100NF | 100nF |  | C0201 | 3227.32 | 2025.99 | 0 | NO
C82 | CC_C0201_DISCRETE_100NF | 100nF |  | C0201 | 2689.32 | 2010.99 | 0 | NO
C83 | CC_C0201_DISCRETE_100NF | 100nF |  | C0201 | 2689.32 | 2030.99 | 0 | NO
C84 | CC_C0201_DISCRETE_100NF | 100nF |  | C0201 | 4695.32 | 3399.99 | 0 | NO
C85 | CC_C0201_DISCRETE_100NF | 100nF |  | C0201 | 4695.32 | 3419.99 | 0 | NO
C86 | CC_C0201_DISCRETE_100NF | 100nF |  | C0201 | 3896.52 | 2241.89 | 0 | NO
C87 | CC_C0201_DISCRETE_100NF | 100nF |  | C0201 | 3896.52 | 2261.89 | 0 | NO
C88 | CC_C0201_DISCRETE_100NF | 100nF |  | C0201 | 3195.72 | 3683.41 | 180 | YES
C89 | CC_C0201_DISCRETE_100NF | 100nF |  | C0201 | 3195.72 | 3663.41 | 180 | YES
C90 | CC_C0201_DISCRETE_100NF | 100nF |  | C0201 | 4696.32 | 3293.99 | 0 | NO
C91 | CC_C0201_DISCRETE_100NF | 100nF |  | C0201 | 4696.32 | 3313.99 | 0 | NO
C92 | CC_C0201_DISCRETE_100NF | 100nF |  | C0201 | 4022.52 | 3682.91 | 180 | YES
C93 | CC_C0201_DISCRETE_100NF | 100nF |  | C0201 | 4022.52 | 3662.91 | 180 | YES
C94 | CC_C0201_DISCRETE_100NF | 100nF |  | C0201 | 2644.65 | 3635 | 270 | NO
C95 | CC_C0402_DISCRETE_1UF | 1uF |  | C0402 | 2126.81 | 2516.58 | 180 | NO
C96 | CC_C0402_DISCRETE_1UF | 1uF |  | C0402 | 2120.9 | 2295.15 | 180 | NO
C97 | CC_C0201_DISCRETE_100NF | 100nF |  | C0201 | 3067.32 | 2008.99 | 0 | NO
C98 | CC_C0201_DISCRETE_100NF | 100nF |  | C0201 | 3067.32 | 2028.99 | 0 | NO
C99 | CC_C0201_DISCRETE_100NF | 100nF |  | C0201 | 3401.32 | 2006.99 | 0 | NO
C100 | CC_C0201_DISCRETE_100NF | 100nF |  | C0201 | 3401.32 | 2026.99 | 0 | NO
C101 | CC_C0201_DISCRETE_100NF | 100nF |  | C0201 | 4216.32 | 2009.99 | 0 | NO
C102 | CC_C0201_DISCRETE_100NF | 100nF |  | C0201 | 4216.32 | 2029.99 | 0 | NO
C103 | CC_C0201_DISCRETE_100NF | 100nF |  | C0201 | 2853.32 | 2008.99 | 0 | NO
C104 | CC_C0201_DISCRETE_100NF | 100nF |  | C0201 | 2853.32 | 2028.99 | 0 | NO
C105 | CC_C0201_DISCRETE_100NF | 100nF |  | C0201 | 2533.32 | 2009.99 | 0 | NO
C106 | CC_C0201_DISCRETE_100NF | 100nF |  | C0201 | 2533.32 | 2029.99 | 0 | NO
C107 | CC_C0201_DISCRETE_100NF | 100nF |  | C0201 | 3898.32 | 2008.99 | 0 | NO
C108 | CC_C0201_DISCRETE_100NF | 100nF |  | C0201 | 3898.32 | 2028.99 | 0 | NO
C109 | CC_C0201_DISCRETE_100NF | 100nF |  | C0201 | 3634.82 | 3682.31 | 180 | YES
C110 | CC_C0201_DISCRETE_100NF | 100nF |  | C0201 | 3634.82 | 3662.31 | 180 | YES
C111 | CC_C0201_DISCRETE_100NF | 100nF |  | C0201 | 2740.68 | 3776.01 | 180 | NO
C112 | CC_C0201_DISCRETE_100NF | 100nF |  | C0201 | 2740.68 | 3757.01 | 180 | NO
C113 | CC_C0201_DISCRETE_100NF | 100nF |  | C0201 | 2988.12 | 3681.61 | 180 | YES
C114 | CC_C0201_DISCRETE_100NF | 100nF |  | C0201 | 2988.12 | 3661.61 | 180 | YES
C115 | CC_C0201_DISCRETE_100NF | 100nF |  | C0201 | 3470.32 | 3683.81 | 180 | YES
C116 | CC_C0201_DISCRETE_100NF | 100nF |  | C0201 | 3470.32 | 3663.81 | 180 | YES
C117 | CC_C0402_100PF | 100pF |  | C0402 | 1509 | 3498.3 | 90 | YES
C118 | CC_C0402_220PF | 220pF |  | C0402 | 1545.3 | 3498.3 | 90 | YES
C119 | CC_C0402_1NF | 1nF |  | C0402 | 1581.7 | 3498.3 | 90 | YES
C120 | CC_C0402_220PF | 220pF |  | C0402 | 2392.28 | 3733.34 | 180 | YES
C121 | CC_C0402_100PF | 100pF |  | C0402 | 2392.28 | 3658.34 | 180 | YES
C122 | CC_C0402_1NF | 1nF |  | C0402 | 2392.28 | 3695.74 | 180 | YES
C123 | CC_C0603_DISCRETE_22UF | 22uF |  | C0603 | 1698.6 | 3639.7 | 0 | NO
C169 | CC_C0603_DISCRETE_22UF | 22uF |  | C0603 | 4054.93 | 3174.98 | 180 | YES
C170 | CC_C0201_DISCRETE_1UF | 1uF |  | C0201 | 3812.76 | 3140.75 | 180 | YES
C171 | CC_C0201_DISCRETE_1UF | 1uF |  | C0201 | 3879.5 | 3091.37 | 90 | YES
C172 | CC_C0201_DISCRETE_1UF | 1uF |  | C0201 | 3792.45 | 3313.59 | 180 | YES
C173 | CC_C0201_DISCRETE_1UF | 1uF |  | C0201 | 3760.13 | 3063.92 | 0 | YES
C174 | CC_C0201_DISCRETE_1UF | 1uF |  | C0201 | 4003.83 | 3464.11 | 180 | YES
C176 | CC_C0201_DISCRETE_100NF | 100nF |  | C0201 | 3885.99 | 3025.99 | 180 | YES
C177 | CC_C0201_DISCRETE_100NF | 100nF |  | C0201 | 3866.44 | 3279.64 | 270 | YES
C178 | CC_C0402_DISCRETE_10UF | 10uF |  | C0402 | 4000 | 3090.5 | 270 | YES
C179 | CC_C0201_DISCRETE_1UF | 1uF |  | C0201 | 4086.09 | 3025.07 | 90 | YES
C180 | CC_C0201_DISCRETE_1UF | 1uF |  | C0201 | 4108.1 | 3321.8 | 270 | YES
C181 | CC_C0201_DISCRETE_100NF | 100nF |  | C0201 | 3237.9 | 2548.1 | 0 | YES
C257 | CC_C0201_DISCRETE_1UF | 1uF |  | C0201 | 3950.24 | 3089.57 | 0 | YES
C258 | CC_C0201_DISCRETE_1UF | 1uF |  | C0201 | 3801.57 | 3228.79 | 270 | YES
C259 | CC_C0201_DISCRETE_1UF | 1uF |  | C0201 | 4008.42 | 2910.45 | 180 | YES
C260 | CC_C0201_DISCRETE_1UF | 1uF |  | C0201 | 3880.24 | 3332.92 | 270 | YES
C261 | CC_C0201_DISCRETE_1UF | 1uF |  | C0201 | 3823.13 | 3323.14 | 270 | YES
C262 | CC_C0201_DISCRETE_1UF | 1uF |  | C0201 | 3133.96 | 2553.4 | 180 | YES
C267 | CC_C0603_DISCRETE_22UF | 22uF |  | C0603 | 3138.99 | 2419.99 | 0 | YES
C268 | CC_C0201_DISCRETE_1UF | 1uF |  | C0201 | 3109.06 | 2756.22 | 0 | YES
C269 | CC_C0201_DISCRETE_1UF | 1uF |  | C0201 | 3622.4 | 2510.21 | 180 | YES
C270 | CC_C0201_DISCRETE_1UF | 1uF |  | C0201 | 3237.43 | 2742.44 | 180 | YES
C271 | CC_C0201_DISCRETE_1UF | 1uF |  | C0201 | 3557.99 | 2781.99 | 90 | YES
C272 | CC_C0201_DISCRETE_1UF | 1uF |  | C0201 | 3569.74 | 2445.13 | 180 | YES
C273 | CC_C0201_DISCRETE_1UF | 1uF |  | C0201 | 3622.59 | 2757.49 | 180 | YES
C274 | CC_C0201_DISCRETE_1UF | 1uF |  | C0201 | 3173.8 | 2771.89 | 90 | YES
C275 | CC_C0201_DISCRETE_100NF | 100nF |  | C0201 | 3184.1 | 2458.94 | 180 | YES
C276 | CC_C0201_DISCRETE_100NF | 100nF |  | C0201 | 3218.49 | 2529.8 | 0 | YES
C277 | CC_C0201_DISCRETE_100NF | 100nF |  | C0201 | 3498.29 | 2833.7 | 0 | YES
C278 | CC_C0201_DISCRETE_1UF | 1uF |  | C0201 | 3232 | 2433.5 | 180 | YES
C281 | CC_C0201_DISCRETE_1UF | 1uF |  | C0201 | 3505.74 | 2671.02 | 90 | YES
C282 | CC_C0201_DISCRETE_1UF | 1uF |  | C0201 | 3097.03 | 2695.27 | 90 | YES
C283 | CC_C0201_DISCRETE_1UF | 1uF |  | C0201 | 3442.49 | 2444.1 | 0 | YES
C284 | CC_C0201_DISCRETE_1UF | 1uF |  | C0201 | 3497.96 | 2791.02 | 0 | YES
C285 | CC_C0201_DISCRETE_100NF | 100nF |  | C0201 | 3651.17 | 2541.13 | 90 | YES
C286 | CC_C0201_DISCRETE_100NF | 100nF |  | C0201 | 3466.65 | 2586.77 | 180 | YES
C287 | CC_C0402_DISCRETE_10UF | 10uF |  | C0402 | 3219.5 | 2805.1 | 90 | YES
C288 | CC_C0201_DISCRETE_1UF | 1uF |  | C0201 | 3471 | 2555.6 | 0 | YES
C289 | CC_C0201_DISCRETE_1UF | 1uF |  | C0201 | 3865.5 | 3384.1 | 270 | YES
C290 | CC_C0201_DISCRETE_1UF | 1uF |  | C0201 | 3960.4 | 3383.91 | 270 | YES
C333 | CC_C0201_DISCRETE_22PF | 22pF |  | C0201 | 2574.58 | 3403.2 | 270 | NO
C336 | CC_C0201_DISCRETE_22PF | 22pF |  | C0201 | 2574.58 | 3316.3 | 90 | NO
C337 | CC_C0201_DISCRETE_18PF | 18pF |  | C0201 | 2692.01 | 3158.71 | 90 | NO
C338 | CC_C0201_DISCRETE_18PF | 18pF |  | C0201 | 2692.09 | 3236.29 | 270 | NO
C373 | CC_C0201_DISCRETE_1UF | 1uF |  | C0201 | 3362 | 3310.2 | 90 | YES
C374 | CC_C0201_DISCRETE_1UF | 1uF |  | C0201 | 3363 | 3272.2 | 90 | YES
C375 | CC_C0201_DISCRETE_1UF | 1uF |  | C0201 | 3184 | 3296.18 | 90 | YES
C457 | CC_C0201_DISCRETE_1UF | 1uF |  | C0201 | 3062.73 | 3165.61 | 180 | YES
C458 | CC_C0201_DISCRETE_10NF | 10nF |  | C0201 | 3062.43 | 3146.75 | 180 | YES
C600 | CC_C0603_DISCRETE_22UF | 22uF |  | C0603 | 2569.7 | 2480.8 | 90 | YES
C601 | CC_C0603_DISCRETE_47UF | 47uF |  | C0603 | 2674.3 | 2821 | 90 | NO
C602 | CC_C0603_DISCRETE_47UF | 47uF |  | C0603 | 2734.2 | 2821 | 90 | NO
C603 | CC_C0603_DISCRETE_22UF | 22uF |  | C0603 | 2679.7 | 2368.8 | 180 | YES
C604 | CC_C0603_DISCRETE_22UF | 22uF |  | C0603 | 2679.7 | 2432.8 | 180 | YES
C605 | CC_C0603_DISCRETE_22UF | 22uF |  | C0603 | 2679.7 | 2495.8 | 180 | YES
C606 | CC_C0603_DISCRETE_47UF | 47uF |  | C0603 | 2615.2 | 2821 | 90 | NO
C607 | CC_C0603_DISCRETE_22UF | 22uF |  | C0603 | 2463.2 | 2307.2 | 90 | YES
C608 | CC_C0402_DISCRETE_2.2UF | 2.2uF |  | C0402 | 2585.7 | 2306.8 | 90 | YES
C609 | CC_C0603_DISCRETE_22UF | 22uF |  | C0603 | 2569.7 | 2598.8 | 270 | YES
C610 | CC_C0603_DISCRETE_22UF | 22uF |  | C0603 | 2679.7 | 2554.8 | 180 | YES
C611 | CC_C0402_DISCRETE_2.2UF | 2.2uF |  | C0402 | 2537.7 | 2358.8 | 270 | YES
C612 | CC_C0603_DISCRETE_47UF | 47uF |  | C0603 | 2483.2 | 2817.6 | 90 | NO
C613 | CC_C0603_DISCRETE_47UF | 47uF |  | C0603 | 2423.2 | 2817.5 | 90 | NO
C614 | CC_C0402_DISCRETE_2.2UF | 2.2uF |  | C0402 | 2801.5 | 2330 | 0 | NO
C615 | CC_C0402_DISCRETE_2.2UF | 2.2uF |  | C0402 | 2801 | 2291.5 | 0 | NO
C616 | CC_C0402_DISCRETE_2.2UF | 2.2uF |  | C0402 | 2800.7 | 2254.8 | 0 | NO
C617 | CC_C0402_DISCRETE_2.2UF | 2.2uF |  | C0402 | 2763.6 | 2187.7 | 270 | NO
C618 | CC_C0402_DISCRETE_2.2UF | 2.2uF |  | C0402 | 2724.6 | 2187.7 | 270 | NO
C619 | CC_C0402_DISCRETE_2.2UF | 2.2uF |  | C0402 | 2685.6 | 2187.7 | 270 | NO
C620 | CC_C0603_DISCRETE_47UF | 47uF |  | C0603 | 2926.4 | 2535.6 | 0 | NO
C621 | CC_C0603_DISCRETE_47UF | 47uF |  | C0603 | 2927.3 | 2477.5 | 0 | NO
C622 | CC_C0402_DISCRETE_2.2UF | 2.2uF |  | C0402 | 2646.6 | 2187.7 | 270 | NO
C623 | CC_C0402_DISCRETE_2.2UF | 2.2uF |  | C0402 | 2607.6 | 2187.7 | 270 | NO
C624 | CC_C0402_DISCRETE_2.2UF | 2.2uF |  | C0402 | 2568.6 | 2187.7 | 270 | NO
C625 | CC_C0402_DISCRETE_2.2UF | 2.2uF |  | C0402 | 2245.1 | 2437.7 | 270 | NO
C626 | CC_C0402_DISCRETE_2.2UF | 2.2uF |  | C0402 | 2529.6 | 2187.7 | 270 | NO
C627 | CC_C0402_DISCRETE_2.2UF | 2.2uF |  | C0402 | 2490.6 | 2187.7 | 270 | NO
C628 | CC_C0603_DISCRETE_47UF | 47uF |  | C0603 | 2893.5 | 2364.6 | 270 | NO
C629 | CC_C0603_DISCRETE_47UF | 47uF |  | C0603 | 2954.6 | 3426.6 | 270 | YES
C630 | CC_C0603_DISCRETE_47UF | 47uF |  | C0603 | 2957.9 | 3284.6 | 90 | YES
C631 | CC_C1210_DISCRETE_100UF | 100uF |  | C1210 | 2556.2 | 3496.9 | 270 | YES
C632 | CC_C0603_DISCRETE_22UF | 22uF |  | C0603 | 2703.6 | 3235 | 180 | YES
C633 | CC_C0603_DISCRETE_22UF | 22uF |  | C0603 | 2701.9 | 3452.1 | 180 | YES
C634 | CC_C0201_DISCRETE_22PF | 22pF |  | C0201 | 2373.6 | 2217.7 | 0 | NO
C638 | CC_C0402_DISCRETE_1UF | 1uF |  | C0402 | 2581.2 | 3331.9 | 0 | YES
C639 | CC_C0201_DISCRETE_22PF | 22pF |  | C0201 | 2420 | 2217.7 | 180 | NO
C640 | CC_C0201_DISCRETE_1UF | 1uF |  | C0201 | 2330.89 | 2351.31 | 180 | NO
C641 | CC_C0201_DISCRETE_220NF | 220nF |  | C0201 | 2330.7 | 2331.3 | 180 | NO
C642 | CC_C0402_DISCRETE_470NF | 470nF |  | C0402 | 2307.8 | 2302.9 | 180 | NO
C643 | CC_C0402_DISCRETE_47NF | 47nF |  | C0402 | 2383.3 | 2686.2 | 90 | NO
C644 | CC_C0402_DISCRETE_470NF | 470nF |  | C0402 | 2723 | 2687.5 | 90 | NO
C673 | CC_C0603_DISCRETE_47UF | 47uF |  | C0603 | 2557.83 | 2820.52 | 90 | NO
C687 | CC_C0603_DISCRETE_47UF | 47uF |  | C0603 | 2926.52 | 2649.97 | 0 | NO
C698 | CC_C0603_DISCRETE_47UF | 47uF |  | C0603 | 2926.52 | 2592.97 | 0 | NO
C1000 | CC_C0603_DISCRETE_22UF | 22uF |  | C0603 | 3914.17 | 2960.1 | 0 | YES
C1001 | CC_C0201_DISCRETE_1UF | 1uF |  | C0201 | 3802.86 | 3049.59 | 270 | YES
C1002 | CC_C0201_DISCRETE_1UF | 1uF |  | C0201 | 3761.27 | 2987.21 | 180 | YES
C1003 | CC_C0201_DISCRETE_1UF | 1uF |  | C0201 | 4016.17 | 3031.32 | 90 | YES
C1004 | CC_C0201_DISCRETE_1UF | 1uF |  | C0201 | 3806.6 | 2938.26 | 90 | YES
C1005 | CC_C0201_DISCRETE_1UF | 1uF |  | C0201 | 4085.92 | 2974.01 | 90 | YES
C1006 | CC_C0201_DISCRETE_1UF | 1uF |  | C0201 | 4035.69 | 3434.8 | 270 | YES
C1007 | CC_C0201_DISCRETE_1UF | 1uF |  | C0201 | 4100.61 | 3382.98 | 270 | YES
C1008 | CC_C0201_DISCRETE_100NF | 100nF |  | C0201 | 3754.6 | 3371.01 | 180 | YES
C1009 | CC_C0201_DISCRETE_100NF | 100nF |  | C0201 | 3788.03 | 3435.31 | 270 | YES
C1010 | CC_C0603_DISCRETE_22UF | 22uF |  | C0603 | 3365.88 | 2480.95 | 90 | YES
C1011 | CC_C0201_DISCRETE_1UF | 1uF |  | C0201 | 3414.42 | 2742.41 | 180 | YES
C1012 | CC_C0201_DISCRETE_1UF | 1uF |  | C0201 | 3276.46 | 2594.93 | 270 | YES
C1013 | CC_C0201_DISCRETE_1UF | 1uF |  | C0201 | 3251.09 | 2785.71 | 270 | YES
C1014 | CC_C0201_DISCRETE_1UF | 1uF |  | C0201 | 3097.44 | 2536.7 | 90 | YES
C1015 | CC_C0201_DISCRETE_1UF | 1uF |  | C0201 | 3520.13 | 2585.56 | 180 | YES
C1020 | CC_C0201_DISCRETE_1UF | 1uF |  | C0201 | 3363.17 | 3347.83 | 270 | YES
C1021 | CC_C0201_DISCRETE_1UF | 1uF |  | C0201 | 3376.9 | 3234.1 | 90 | YES
C1023 | CC_C0201_DISCRETE_1UF | 1uF |  | C0201 | 3262.33 | 3235.87 | 90 | YES
C1024 | CC_C0201_DISCRETE_1UF | 1uF |  | C0201 | 3239.17 | 3340.93 | 270 | YES
C1026 | CC_C0201_DISCRETE_100NF | 100nF |  | C0201 | 3228.47 | 3169.57 | 0 | YES
C1027 | CC_C0201_DISCRETE_100NF | 100nF |  | C0201 | 3286.93 | 3279.97 | 90 | YES
C1028 | CC_C0201_DISCRETE_1UF | 1uF |  | C0201 | 3165 | 3294.2 | 270 | YES
C1029 | CC_C0201_DISCRETE_1UF | 1uF |  | C0201 | 3184.01 | 3236.1 | 270 | YES
C1030 | CC_C0201_DISCRETE_1UF | 1uF |  | C0201 | 3236.07 | 3235.71 | 90 | YES
C1031 | CC_C0201_DISCRETE_1UF | 1uF |  | C0201 | 3213 | 3312.2 | 270 | YES
C1034 | CC_C0402_DISCRETE_10UF | 10uF |  | C0402 | 3137 | 3309.9 | 270 | YES
C1035 | CC_C0402_DISCRETE_10UF | 10uF |  | C0402 | 3043.03 | 3294.59 | 270 | YES
C1036 | CC_C0402_DISCRETE_10UF | 10uF |  | C0402 | 3080 | 3294.7 | 270 | YES
C1037 | CC_C0603_DISCRETE_47UF | 47uF |  | C0603 | 3323.7 | 3305 | 270 | YES
C1038 | CC_C0603_DISCRETE_47UF | 47uF |  | C0603 | 3090.57 | 3398.81 | 270 | YES
C1039 | CC_C0603_DISCRETE_47UF | 47uF |  | C0603 | 3033.57 | 3398.51 | 270 | YES
C1040 | CC_C0201_DISCRETE_1UF | 1uF |  | C0201 | 3258.01 | 3279.81 | 90 | YES
C1041 | CC_C0201_DISCRETE_1UF | 1uF |  | C0201 | 3286.99 | 3330.19 | 270 | YES
C1042 | CC_C0201_DISCRETE_1UF | 1uF |  | C0201 | 3257.01 | 3317.8 | 90 | YES
C1043 | CC_C0201_DISCRETE_1UF | 1uF |  | C0201 | 3238.01 | 3299.8 | 90 | YES
C1044 | CC_C0201_DISCRETE_1UF | 1uF |  | C0201 | 3165 | 3334.81 | 90 | YES
C1045 | CC_C0201_DISCRETE_1UF | 1uF |  | C0201 | 3193 | 3336.19 | 90 | YES
C1046 | CC_C0201_DISCRETE_1UF | 1uF |  | C0201 | 3208.05 | 3236.22 | 90 | YES
C1047 | CC_C0201_DISCRETE_1UF | 1uF |  | C0201 | 3191.81 | 3265 | 0 | YES
C1048 | CC_C0201_DISCRETE_1UF | 1uF |  | C0201 | 3229.81 | 3271 | 180 | YES
C1051 | CC_C0201_DISCRETE_100NF | 100nF |  | C0201 | 3287.99 | 3421.19 | 270 | YES
C1052 | CC_C0201_DISCRETE_1UF | 1uF |  | C0201 | 3255 | 3421.19 | 270 | YES
C1053 | CC_C0201_DISCRETE_1UF | 1uF |  | C0201 | 3223.99 | 3421.19 | 270 | YES
C1055 | CC_C0201_DISCRETE_1UF | 1uF |  | C0201 | 3212 | 3378.2 | 270 | YES
C1056 | CC_C0201_DISCRETE_1UF | 1uF |  | C0201 | 3275 | 3378.19 | 270 | YES
C1057 | CC_C0201_DISCRETE_100NF | 100nF |  | C0201 | 3242 | 3378.19 | 270 | YES
C1059 | CC_C0201_DISCRETE_1UF | 1uF |  | C0201 | 3198 | 3157.2 | 90 | YES
C1060 | CC_C0201_DISCRETE_1UF | 1uF |  | C0201 | 3209.9 | 3128.3 | 180 | YES
C1062 | CC_C0201_DISCRETE_100NF | 100nF |  | C0201 | 3222.6 | 3197.71 | 270 | YES
C1066 | CC_C0201_DISCRETE_1UF | 1uF |  | C0201 | 3198.3 | 3087.98 | 90 | YES
C1067 | CC_C0402_DISCRETE_10UF | 10uF |  | C0402 | 3134.5 | 3501 | 270 | YES
C1068 | CC_C0201_DISCRETE_1UF | 1uF |  | C0201 | 3467.31 | 3369.5 | 180 | YES
C1069 | CC_C0201_DISCRETE_1UF | 1uF |  | C0201 | 3162 | 3430.19 | 270 | YES
C1070 | CC_C0201_DISCRETE_1UF | 1uF |  | C0201 | 3410.5 | 3394.19 | 270 | YES
C1071 | CC_C0201_DISCRETE_1UF | 1uF |  | C0201 | 3130 | 3430.19 | 270 | YES
C1072 | CC_C0201_DISCRETE_1UF | 1uF |  | C0201 | 3382 | 3394.2 | 270 | YES
C1073 | CC_C0201_DISCRETE_100NF | 100nF |  | C0201 | 3153.3 | 3373.12 | 270 | YES
C1074 | CC_C0201_DISCRETE_100NF | 100nF |  | C0201 | 3350 | 3394.19 | 270 | YES
C1075 | CC_C0402_DISCRETE_10UF | 10uF |  | C0402 | 3266.8 | 3006.6 | 90 | YES
C1076 | CC_C0201_DISCRETE_1UF | 1uF |  | C0201 | 3269.13 | 3099.59 | 180 | YES
C1077 | CC_C0201_DISCRETE_1UF | 1uF |  | C0201 | 3269.22 | 3080.11 | 180 | YES
C1083 | CC_C0201_DISCRETE_1UF | 1uF |  | C0201 | 3089.79 | 3233.6 | 0 | YES
C1084 | CC_C0201_DISCRETE_100NF | 100nF |  | C0201 | 3117 | 3106.4 | 90 | YES
C1085 | CC_C0402_DISCRETE_10UF | 10uF |  | C0402 | 3202.8 | 3028 | 0 | YES
C1086 | CC_C0201_DISCRETE_1UF | 1uF |  | C0201 | 3228.81 | 3077 | 180 | YES
C1087 | CC_C0201_DISCRETE_1UF | 1uF |  | C0201 | 3228.8 | 3096 | 180 | YES
C1091 | CC_C0201_DISCRETE_1UF | 1uF |  | C0201 | 3170.18 | 3188.98 | 0 | YES
C1092 | CC_C0201_DISCRETE_1UF | 1uF |  | C0201 | 3170.19 | 3151.04 | 0 | YES
C1093 | CC_C0201_DISCRETE_100NF | 100nF |  | C0201 | 3170.17 | 3169.06 | 0 | YES
C1095 | CC_C0201_DISCRETE_1UF | 1uF |  | C0201 | 3142.41 | 3167.91 | 270 | YES
C1097 | CC_C0201_DISCRETE_1UF | 1uF |  | C0201 | 3269.5 | 3198.39 | 90 | YES
C1098 | CC_C0201_DISCRETE_100NF | 100nF |  | C0201 | 3251.06 | 3198.56 | 90 | YES
C1100 | CC_C0201_DISCRETE_1UF | 1uF |  | C0201 | 3413.6 | 3356.2 | 90 | YES
C1101 | CC_C0201_DISCRETE_1UF | 1uF |  | C0201 | 3289.6 | 3199.49 | 90 | YES
C1103 | CC_C0201_DISCRETE_1UF | 1uF |  | C0201 | 3205.2 | 3198.59 | 90 | YES
C1106 | CC_C0201_DISCRETE_1UF | 1uF |  | C0201 | 3228.49 | 3148.5 | 0 | YES
C1109 | CC_C0201_DISCRETE_100NF | 100nF |  | C0201 | 3347.1 | 3195.2 | 180 | YES
C1110 | CC_C0201_DISCRETE_1UF | 1uF |  | C0201 | 3095.4 | 3181.09 | 90 | YES
C1111 | CC_C0201_DISCRETE_1UF | 1uF |  | C0201 | 3141.6 | 3206.5 | 270 | YES
C1114 | CC_C0201_DISCRETE_1UF | 1uF |  | C0201 | 3117 | 3144.38 | 90 | YES
C1115 | CC_EMIFIL_3P_EMIFIL_0402_3P_DISCRETE_4.3UF | 4.3uF |  | EMIFIL_0402_3P | 3441 | 3220.5 | 90 | YES
C1116 | CC_EMIFIL_3P_EMIFIL_0402_3P_DISCRETE_4.3UF | 4.3uF |  | EMIFIL_0402_3P | 3420 | 3149.5 | 0 | YES
C1117 | CC_EMIFIL_3P_EMIFIL_0402_3P_DISCRETE_4.3UF | 4.3uF |  | EMIFIL_0402_3P | 3337.1 | 3143.6 | 0 | YES
C1118 | CC_EMIFIL_3P_EMIFIL_0402_3P_DISCRETE_4.3UF | 4.3uF |  | EMIFIL_0402_3P | 3434.3 | 3289 | 90 | YES
C1119 | CC_C0603_DISCRETE_22UF | 22uF |  | C0603 | 3777 | 3183 | 0 | YES
C1120 | CC_C0603_DISCRETE_22UF | 22uF |  | C0603 | 3058.5 | 2525 | 90 | YES
C1122 | CC_C0204_DISCRETE_1UF | 1uF |  | C0204 | 3395 | 3103 | 90 | YES
C1123 | CC_C0204_DISCRETE_1UF | 1uF |  | C0204 | 3452 | 3103 | 90 | YES
C1124 | CC_C0204_DISCRETE_1UF | 1uF |  | C0204 | 3316 | 3101 | 90 | YES
C1125 | CC_C0204_DISCRETE_1UF | 1uF |  | C0204 | 3483 | 3306.5 | 180 | YES
C1127 | CC_C0204_DISCRETE_1UF | 1uF |  | C0204 | 3482 | 3156 | 180 | YES
C1128 | CC_C0204_DISCRETE_1UF | 1uF |  | C0204 | 3485.3 | 3212 | 180 | YES
C1129 | CC_C0603_DISCRETE_22UF | 22uF |  | C0603 | 3541 | 3130 | 90 | YES
C1130 | CC_C0603_DISCRETE_22UF | 22uF |  | C0603 | 3657 | 3130 | 90 | YES
C1133 | CC_EMIFIL_3P_EMIFIL_0402_3P_DISCRETE_4.3UF | 4.3uF |  | EMIFIL_0402_3P | 3395.3 | 3290.6 | 90 | YES
C1134 | CC_EMIFIL_3P_EMIFIL_0402_3P_DISCRETE_4.3UF | 4.3uF |  | EMIFIL_0402_3P | 3404 | 3221 | 90 | YES
C1135 | CC_C0201_DISCRETE_1UF | 1uF |  | C0201 | 3379.4 | 3148.7 | 90 | YES
C1136 | CC_C0201_DISCRETE_1UF | 1uF |  | C0201 | 3326.21 | 3177 | 180 | YES
C1137 | CC_C0201_DISCRETE_1UF | 1uF |  | C0201 | 3404.19 | 3182.5 | 180 | YES
C1138 | CC_C0201_DISCRETE_1UF | 1uF |  | C0201 | 3365.19 | 3177 | 0 | YES
C1140 | CC_C0201_DISCRETE_100NF | 100nF |  | C0201 | 3373.61 | 3052 | 180 | YES
C1141 | CC_C0201_DISCRETE_1UF | 1uF |  | C0201 | 3307.9 | 3050.2 | 180 | YES
C1142 | CC_C0201_DISCRETE_1UF | 1uF |  | C0201 | 3373.31 | 3070.7 | 180 | YES
C1144 | CC_C0201_DISCRETE_1UF | 1uF |  | C0201 | 3477.5 | 3258.2 | 270 | YES
C1147 | CC_C0201_DISCRETE_1UF | 1uF |  | C0201 | 3307.71 | 3068.6 | 180 | YES
C1150 | CC_C0201_DISCRETE_1UF | 1uF |  | C0201 | 3256.91 | 3159.31 | 270 | YES
C1151 | CC_EMIFIL_3P_EMIFIL_0402_3P_DISCRETE_22NF | 22nF |  | EMIFIL_0402_3P | 3140 | 3245 | 180 | YES
D1 | D_ESD_DIFFPAIR_USON10_0D5_2D5X1X0D5MM_DISCRETE_TPD4E05U06DQAR | TPD4E05U06DQAR |  | USON10_0D5_2D5X1X0D5MM | 1828.71 | 3079.74 | 90 | YES
D2 | D_ESD_DIFFPAIR_USON10_0D5_2D5X1X0D5MM_DISCRETE_TPD4E05U06DQAR | TPD4E05U06DQAR |  | USON10_0D5_2D5X1X0D5MM | 1828.71 | 2951.26 | 90 | YES
D3 | D_SOD_523_DISCRETE_RB520S30T1G | RB520S30T1G |  | SOD_523 | 4525 | 2845 | 0 | YES
D4 | D_ESD_DIFFPAIR_USON10_0D5_2D5X1X0D5MM_DISCRETE_TPD4E05U06DQAR | TPD4E05U06DQAR |  | USON10_0D5_2D5X1X0D5MM | 4476.29 | 3111.37 | 270 | NO
D5 | D_ESD_DIFFPAIR_USON10_0D5_2D5X1X0D5MM_DISCRETE_TPD4E05U06DQAR | TPD4E05U06DQAR |  | USON10_0D5_2D5X1X0D5MM | 4476.29 | 2993 | 270 | NO
D6 | DIODE TVS BI-DIR_D0402_DISCRETE_ESDPSA0402V05 | ESDPSA0402V05 |  | D0402 | 4515 | 2915 | 270 | YES
D7 | DIODE TVS BI-DIR_D0402_DISCRETE_ESDPSA0402V05 | ESDPSA0402V05 |  | D0402 | 4555 | 2915 | 270 | YES
D8 | DIODE TVS BI-DIR_D0402_DISCRETE_ESDPSA0402V05 | ESDPSA0402V05 |  | D0402 | 4635 | 2915 | 270 | YES
D9 | D_SOD_523_DISCRETE_RB520S30T1G | RB520S30T1G |  | SOD_523 | 4525 | 2713.97 | 0 | YES
D10 | DIODE TVS BI-DIR_D0402_DISCRETE_ESDPSA0402V05 | ESDPSA0402V05 |  | D0402 | 4595 | 2915 | 270 | YES
D11 | DIODE TVS BI-DIR_D0402_DISCRETE_ESDPSA0402V05 | ESDPSA0402V05 |  | D0402 | 4522.96 | 3263.98 | 270 | NO
D12 | D_ESD_DIFFPAIR_USON10_0D5_2D5X1X0D5MM_DISCRETE_TPD4E02B04DQAR | TPD4E02B04DQAR |  | USON10_0D5_2D5X1X0D5MM | 1299.29 | 2121.63 | 270 | NO
D13 | D_SOD_523_DISCRETE_RB520S30T1G | RB520S30T1G |  | SOD_523 | 4525 | 2798.97 | 0 | YES
D14 | DIODE TVS BI-DIR_D0402_DISCRETE_TPD1E1B04DPYR | TPD1E1B04DPYR |  | D0402 | 4103.68 | 2814.08 | 180 | NO
D15 | DIODE TVS BI-DIR_D0402_DISCRETE_TPD1E1B04DPYR | TPD1E1B04DPYR |  | D0402 | 4102.56 | 2463.22 | 0 | NO
D16 | DIODE TVS BI-DIR_D0402_DISCRETE_TPD1E1B04DPYR | TPD1E1B04DPYR |  | D0402 | 4102.6 | 2503.22 | 0 | NO
D17 | DIODE TVS BI-DIR_D0402_DISCRETE_TPD1E1B04DPYR | TPD1E1B04DPYR |  | D0402 | 4102.64 | 2543.22 | 0 | NO
D18 | DIODE TVS BI-DIR_D0402_DISCRETE_TPD1E1B04DPYR | TPD1E1B04DPYR |  | D0402 | 4102.68 | 2638.22 | 0 | NO
D19 | DIODE TVS BI-DIR_D0402_DISCRETE_ESDPSA0402V05 | ESDPSA0402V05 |  | D0402 | 1317.38 | 2350.84 | 180 | NO
D20 | DIODE TVS BI-DIR_D0402_DISCRETE_ESDPSA0402V05 | ESDPSA0402V05 |  | D0402 | 1317.38 | 2311.84 | 180 | NO
D21 | DIODE TVS BI-DIR_D0402_DISCRETE_ESDPSA0402V05 | ESDPSA0402V05 |  | D0402 | 1317.38 | 2271.84 | 180 | NO
D22 | DIODE TVS BI-DIR_DO_214AA_SMB_DISCRETE_SMBJ5.0CA-TR | SMBJ5.0CA-TR |  | DO_214AA_SMB | 1393.7 | 2462.4 | 180 | NO
D23 | D_ZENER_SOD_523_DISCRETE_MM5Z3V3T1G | MM5Z3V3T1G |  | SOD_523 | 1724.03 | 2325.78 | 90 | NO
D24 | D_DO_214AC_SMA_DISCRETE_B130L-13-F | B130L-13-F |  | DO_214AC_SMA | 4406.66 | 3540.92 | 270 | NO
D25 | DIODE TVS BI-DIR_DO_214AA_SMB_DISCRETE_SMBJ24CA | SMBJ24CA |  | DO_214AA_SMB | 1638.9 | 3675.8 | 90 | YES
D26 | DIODE TVS BI-DIR_D0402_DISCRETE_TPD1E1B04DPYR | TPD1E1B04DPYR |  | D0402 | 4103.36 | 2725.88 | 0 | NO
D27 | DIODE TVS BI-DIR_D0402_DISCRETE_TPD1E1B04DPYR | TPD1E1B04DPYR |  | D0402 | 4103.72 | 2768.22 | 0 | NO
D28 | D_DO_214AC_SMA_DISCRETE_B130L-13-F | B130L-13-F |  | DO_214AC_SMA | 4523.36 | 3540.92 | 270 | NO
D29 | DIODE TVS BI-DIR_D0402_DISCRETE_TPD1E1B04DPY | TPD1E1B04DPY |  | D0402 | 1381.7 | 4053.5 | 0 | NO
D30 | DIODE TVS BI-DIR_D0402_DISCRETE_TPD1E1B04DPY | TPD1E1B04DPY |  | D0402 | 1326 | 4032.7 | 270 | NO
D31 | DIODE TVS BI-DIR_D0402_DISCRETE_TPD1E1B04DPY | TPD1E1B04DPY |  | D0402 | 1245.4 | 4032.7 | 270 | NO
D32 | D_SOD_523_DISCRETE_RB520S30T1G | RB520S30T1G |  | SOD_523 | 1641.21 | 3878.67 | 0 | YES
D33 | DIODE TVS BI-DIR_D0402_DISCRETE_TPD1E1B04DPY | TPD1E1B04DPY |  | D0402 | 1381.54 | 4011.72 | 0 | NO
D34 | DIODE TVS BI-DIR_D0402_DISCRETE_TPD1E1B04DPY | TPD1E1B04DPY |  | D0402 | 1285.2 | 4032.7 | 270 | NO
D35 | D_SOD_523_DISCRETE_RB520S30T1G | RB520S30T1G |  | SOD_523 | 1642.74 | 3833.67 | 0 | YES
D36 | DIODE TVS BI-DIR_D0402_DISCRETE_ESDPSA0402V05 | ESDPSA0402V05 |  | D0402 | 1493.1 | 2040.2 | 270 | YES
D37 | DIODE TVS BI-DIR_D0402_DISCRETE_ESDPSA0402V05 | ESDPSA0402V05 |  | D0402 | 1495.8 | 2415 | 270 | YES
D38 | D_SOD_523_DISCRETE_RB520S30T1G | RB520S30T1G |  | SOD_523 | 4525 | 2757.39 | 0 | YES
FB1 | FB_L0603_DISCRETE_120R | 120R |  | L0603 | 1923.27 | 2568.02 | 0 | NO
FB2 | FB_L0402_DISCRETE_120R | 120R |  | L0402 | 2120.8 | 2884.7 | 0 | NO
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

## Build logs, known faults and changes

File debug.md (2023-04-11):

# Debug port

To debug the board we have two options,
1. UART
2. JTAG

Below are the details on how to use these interfaces.

## UART debug port

With `v0.2 (DVT)` of BeagleV Ahead board you have BeagleBone Black style header pins but due to some unknown reason it's not compatible with the usual FTDI debug cable like [this](https://www.adafruit.com/product/70). To make the connection, you can use FTDI module like [this](https://www.amazon.in/HiLetgo-Ft232rl-Serial-Adapter-Arduino/dp/B00IJXZQ7C/) to only make the connections listed below:

1. Connect `TXD` pin of FTDI module to `RX` pin of BeagleV Ahead.
2. Connect `RXD` pin of FTDI module to `TX` pin of BeagleV Ahead.
3. Connect `GND` pin of FTDI module to `GND` pin of BeagleV Ahead.

After making the connections, you can use serial communication tools like `tio` to see the boot log and get access to the shell. Using `tio` is very simple, you just have to know the serial port of the FTDI module. To identify the serial port of your FTDI module you can see [this](https://www.mathworks.com/help/supportpkg/arduinoio/ug/find-arduino-port-on-windows-mac-and-linux.html) simple guide. Now execute the command below to make the connection:

```
[lorforlinux@fedora ~] $ tio /dev/ttyUSB0
```

I am using Linux and serial port for my FTDI module is thus I used `/dev/ttyUSB0` as port name you may have different name so please update the command accordingly.

## JTAG

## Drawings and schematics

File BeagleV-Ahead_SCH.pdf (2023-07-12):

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
VER # | REVIEWED BY DATE | AUTHOR DESCRIPTION OF CHANGES
1.0 | April 20, 2023 | Production release. | qxn
Title: Size: | Document Number: | Rev: Draw By: | Date: | Sheet: | of
https://www.seeedstudio.com A3 | v1.0
qxn | Thursday, April 20, 2023 | 1 | 26 BeagleV-Ahead
001_Revision History V1 | Title: Size: | Document Number: | Rev: Draw By: | Date: | Sheet: | of
https://www.seeedstudio.com A3 | v1.0
qxn | Thursday, April 20, 2023 | 1 | 26 BeagleV-Ahead
001_Revision History V1 | Title: Size: | Document Number: | Rev: Draw By: | Date: | Sheet: | of
https://www.seeedstudio.com A3 | v1.0
qxn | Thursday, April 20, 2023 | 1 | 26 BeagleV-Ahead

001_Revision History V1

Power Sink/ Power Source | Gigabit Ethernet RTL8211F-CG WiFi/2.4G BT5.0 AP6203BM
3-pin debug UART connector | Buffer | USB2/USB3

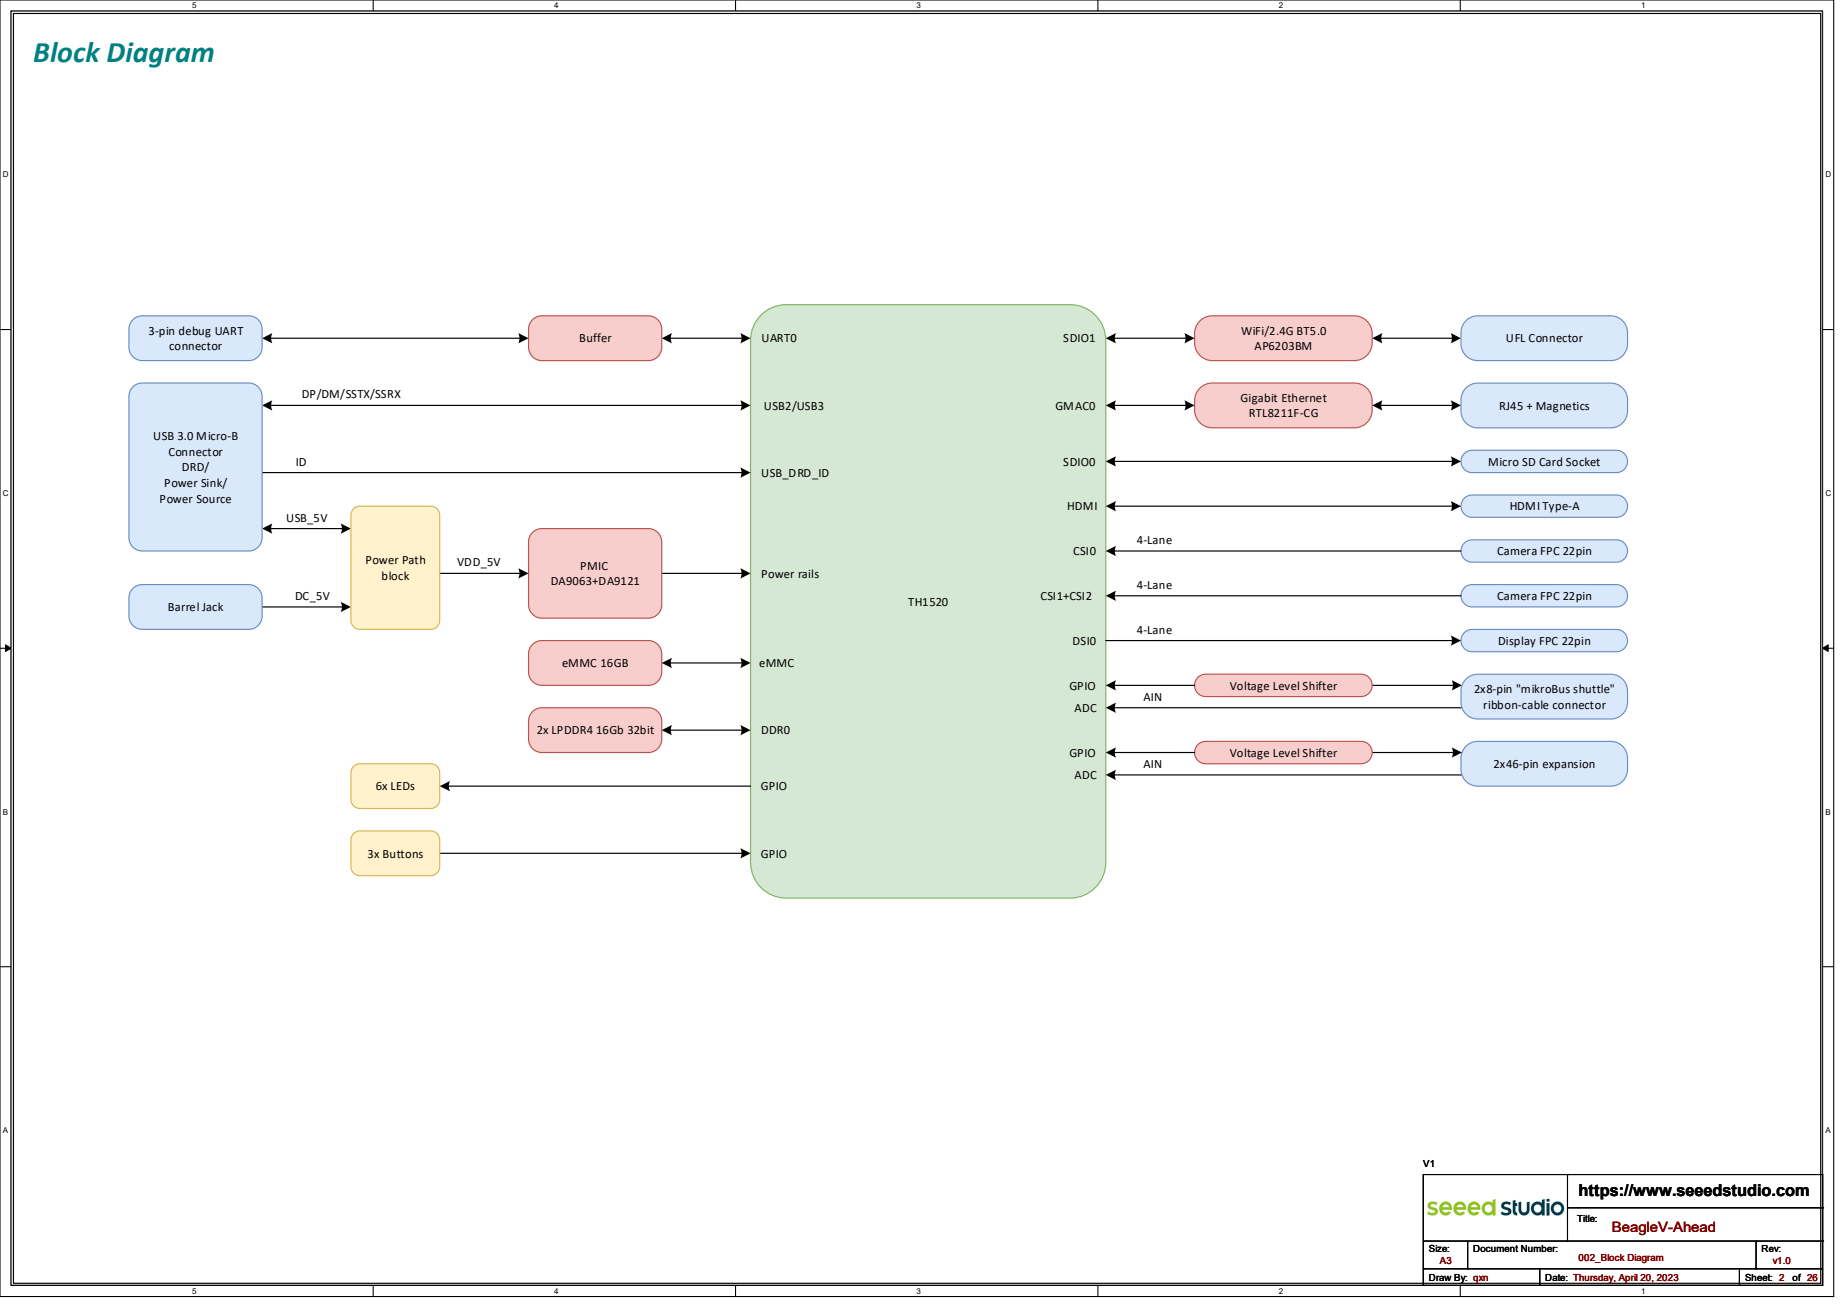
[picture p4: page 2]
eMMC 16GB; 2x LPDDR4 16Gb 32bit; 2x46-pin expansion; 6x LEDs 3x Buttons; Barrel Jack; HDMI Type-A; PMIC DA9063+DA9121; GMAC0; SDIO1; RJ45 + Magnetics UFL Connector; eMMC DDR0; SDIO0 HDMI CSI0; 4-Lane CSI1+CSI2; Camera FPC 22pin; 4-Lane DSI0; Display FPC 22pin; 4-Lane; 2x8-pin "mikroBus shuttle" ribbon-cable connector GPIO; ADC; AIN; GPIO; UART0 DC_5V; USB_5V; Power rails Power Path block; VDD_5V; USB_DRD_ID; Block Diagram; https://www.seeedstudio.com A3; qxn; Thursday, April 20, 2023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

DP/DM/SSTX/SSRX

USB 3.0 Micro-B Connector DRD/

Micro SD Card Socket Camera FPC 22pin GPIO

Voltage Level Shifter

# Power tree

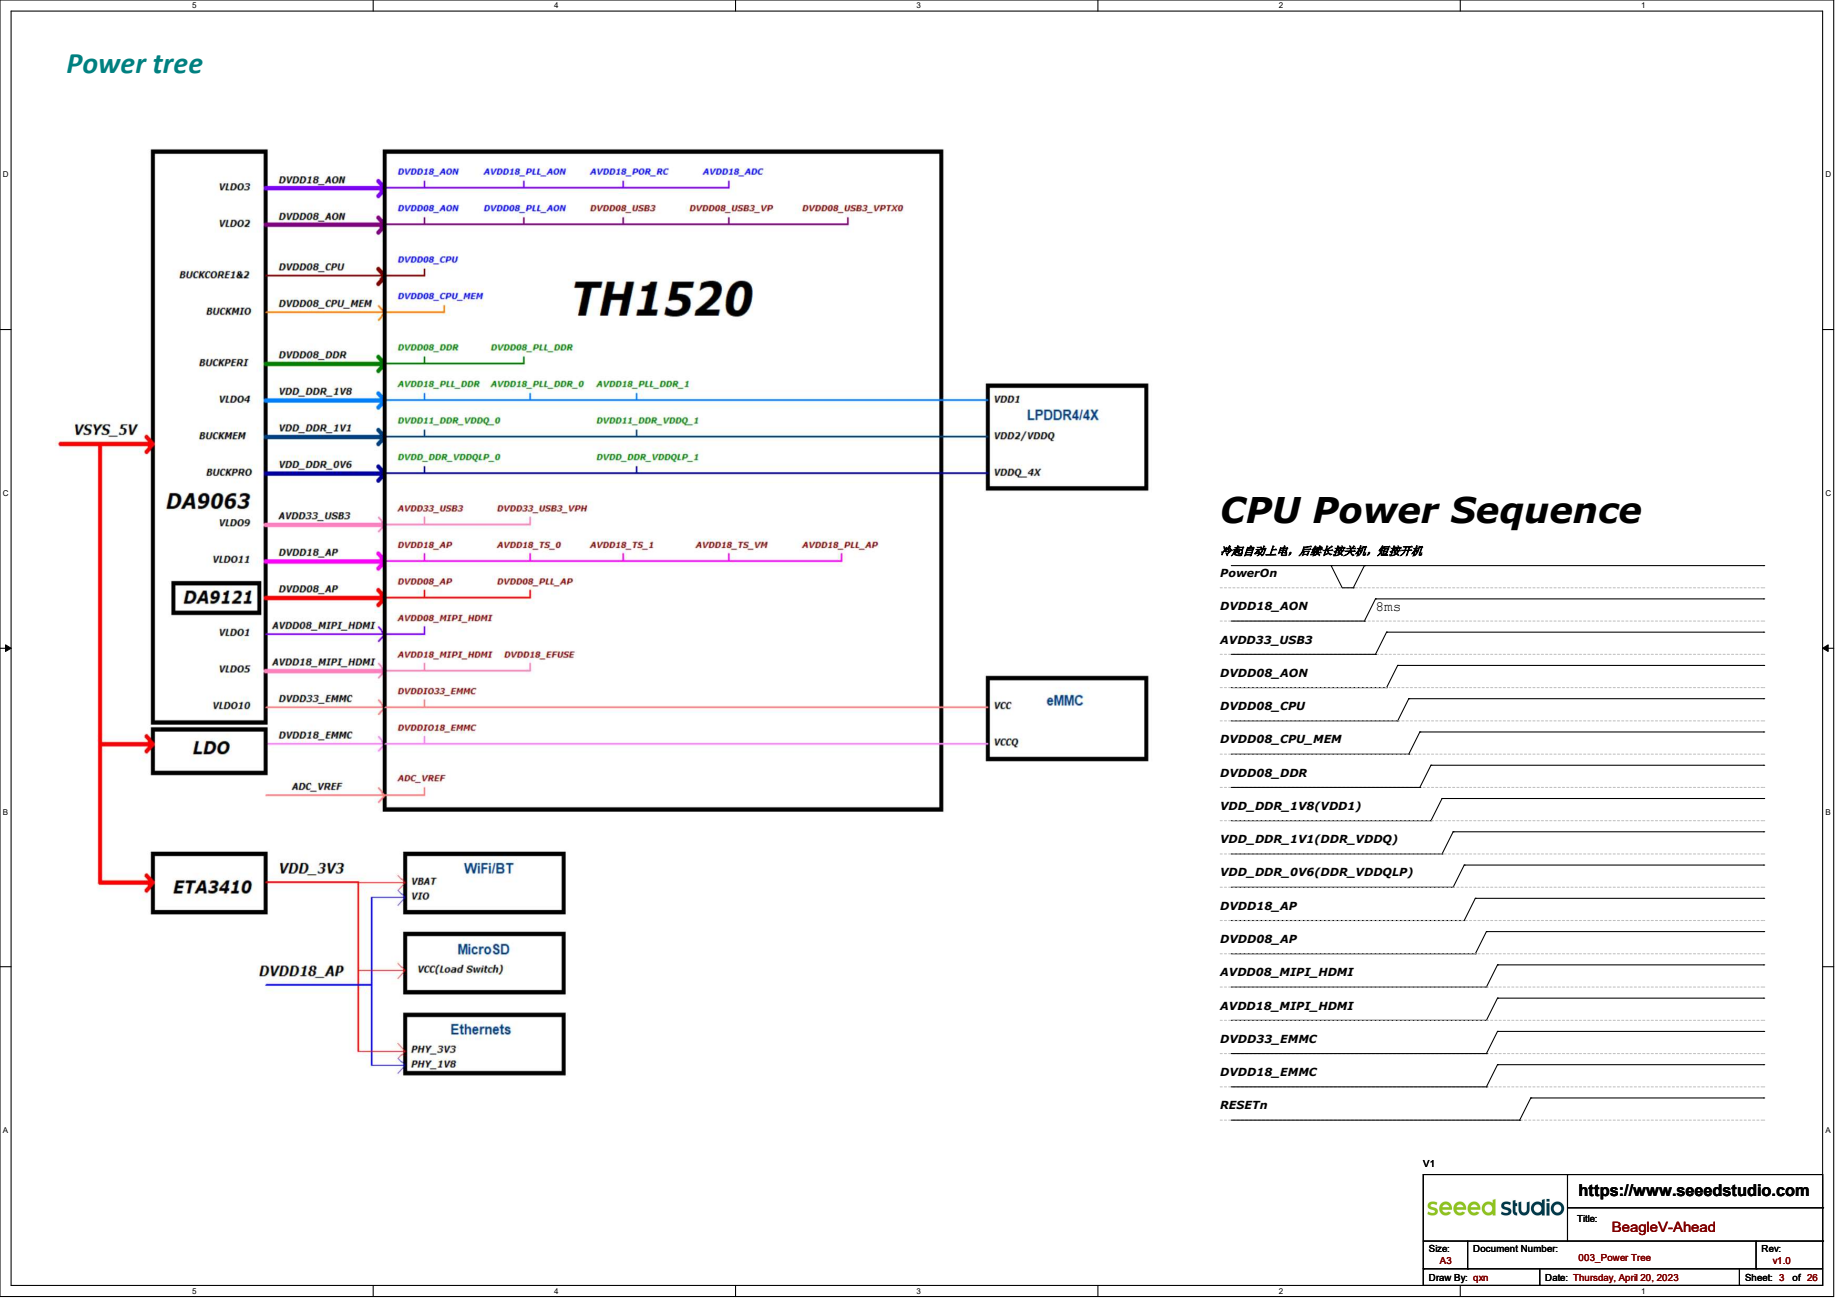
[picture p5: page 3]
DVDD18_EMMC; DVDD18_AON; DVDD08_AP; DVDD08_CPU; AVDD18_MIPI_HDMI; DVDD08_CPU_MEM; VDD_DDR_0V6(DDR_VDDQLP); DVDD08_DDR; DVDD18_AP; DVDD08_AON; RESETn; DVDD33_EMMC; VDD_DDR_1V8(VDD1); VDD_DDR_1V1(DDR_VDDQ); AVDD33_USB3; AVDD08_MIPI_HDMI; Title: Size:; Document Number:; Rev: Draw By:; Date:; Sheet:; https://www.seeedstudio.com A3; qxn; Thursday, April 20, 2023; 26 BeagleV-Ahead; 003_Power Tree V1

CPU Power Sequence 8ms

冷起自动上电，后续长按关机，短按开机
PowerOn

# I2C Usage Diagram

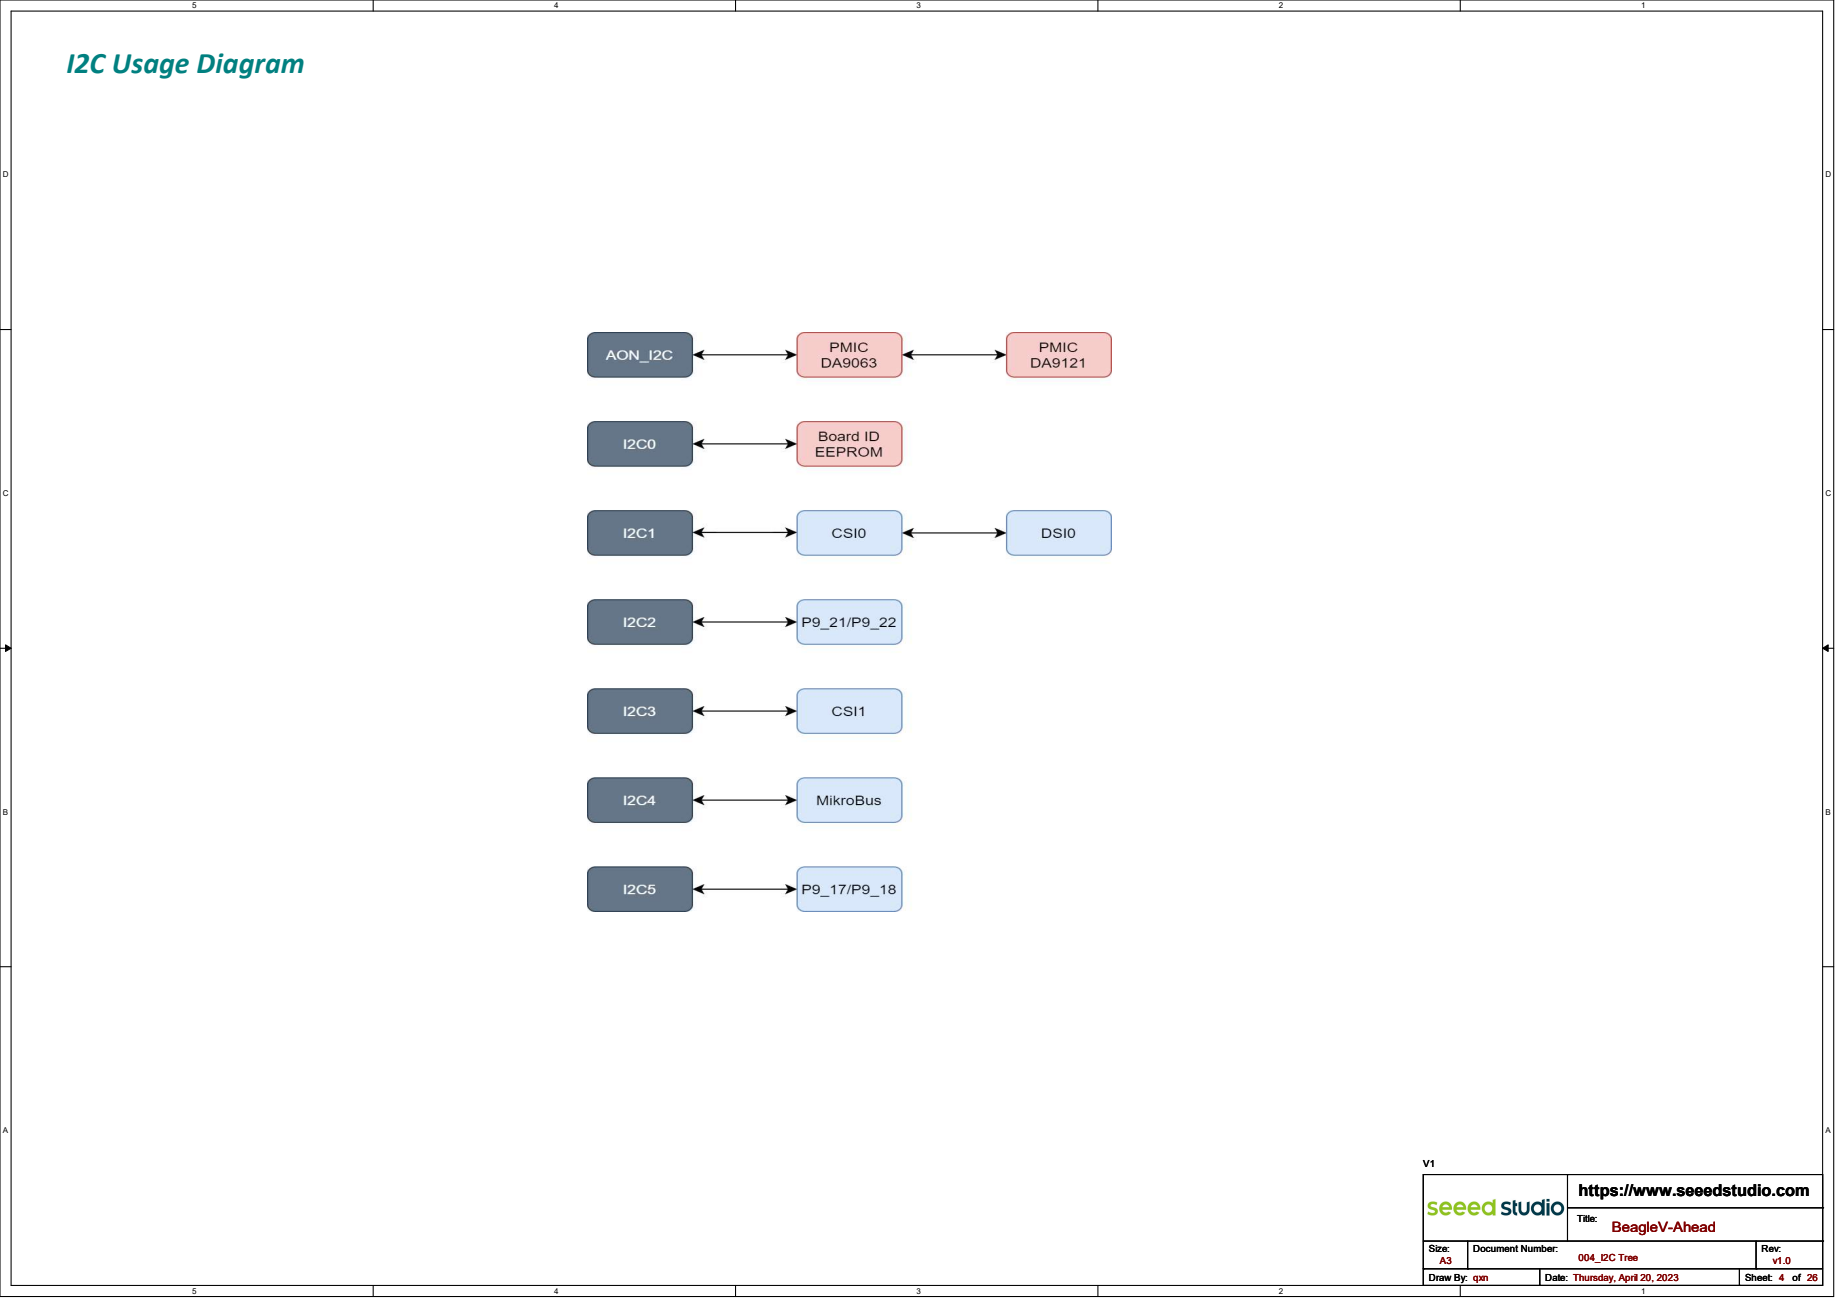
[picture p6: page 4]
https://www.seeedstudio.com A3; qxn; Thursday, April 20, 2023; 26 BeagleV-Ahead; 004_I2C Tree V1; Title: Size:; Document Number:; Rev: Draw By:; Date:; Sheet:

# SoC Power

DVDD08_AP | DVDD08_CPU

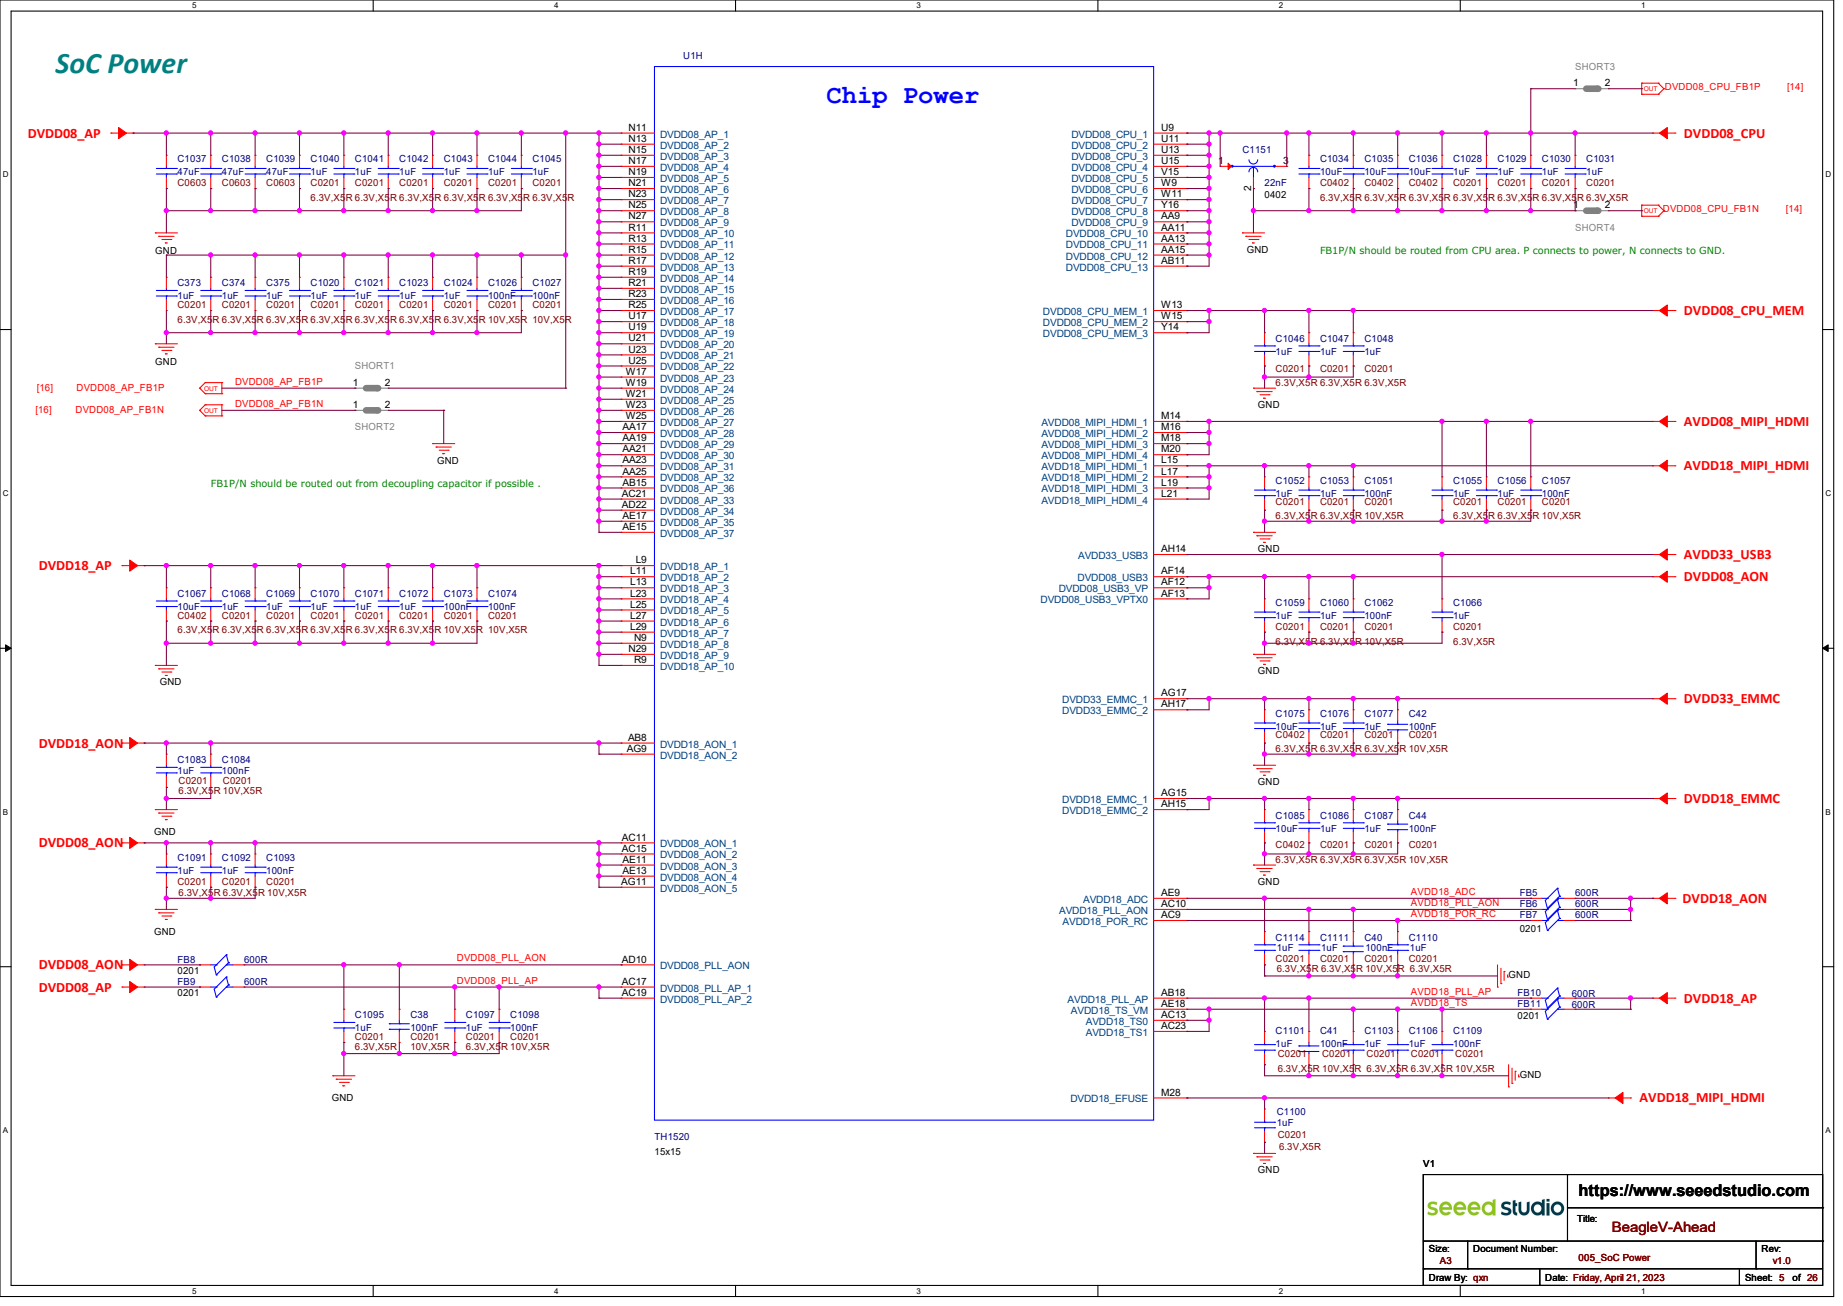
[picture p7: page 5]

FB1P/N should be routed from CPU area. P connects to power, N connects to GND.

FB1P/N should be routed out from decoupling capacitor if possible .

# SoC DDR Power

## VDD_DDR_1V1

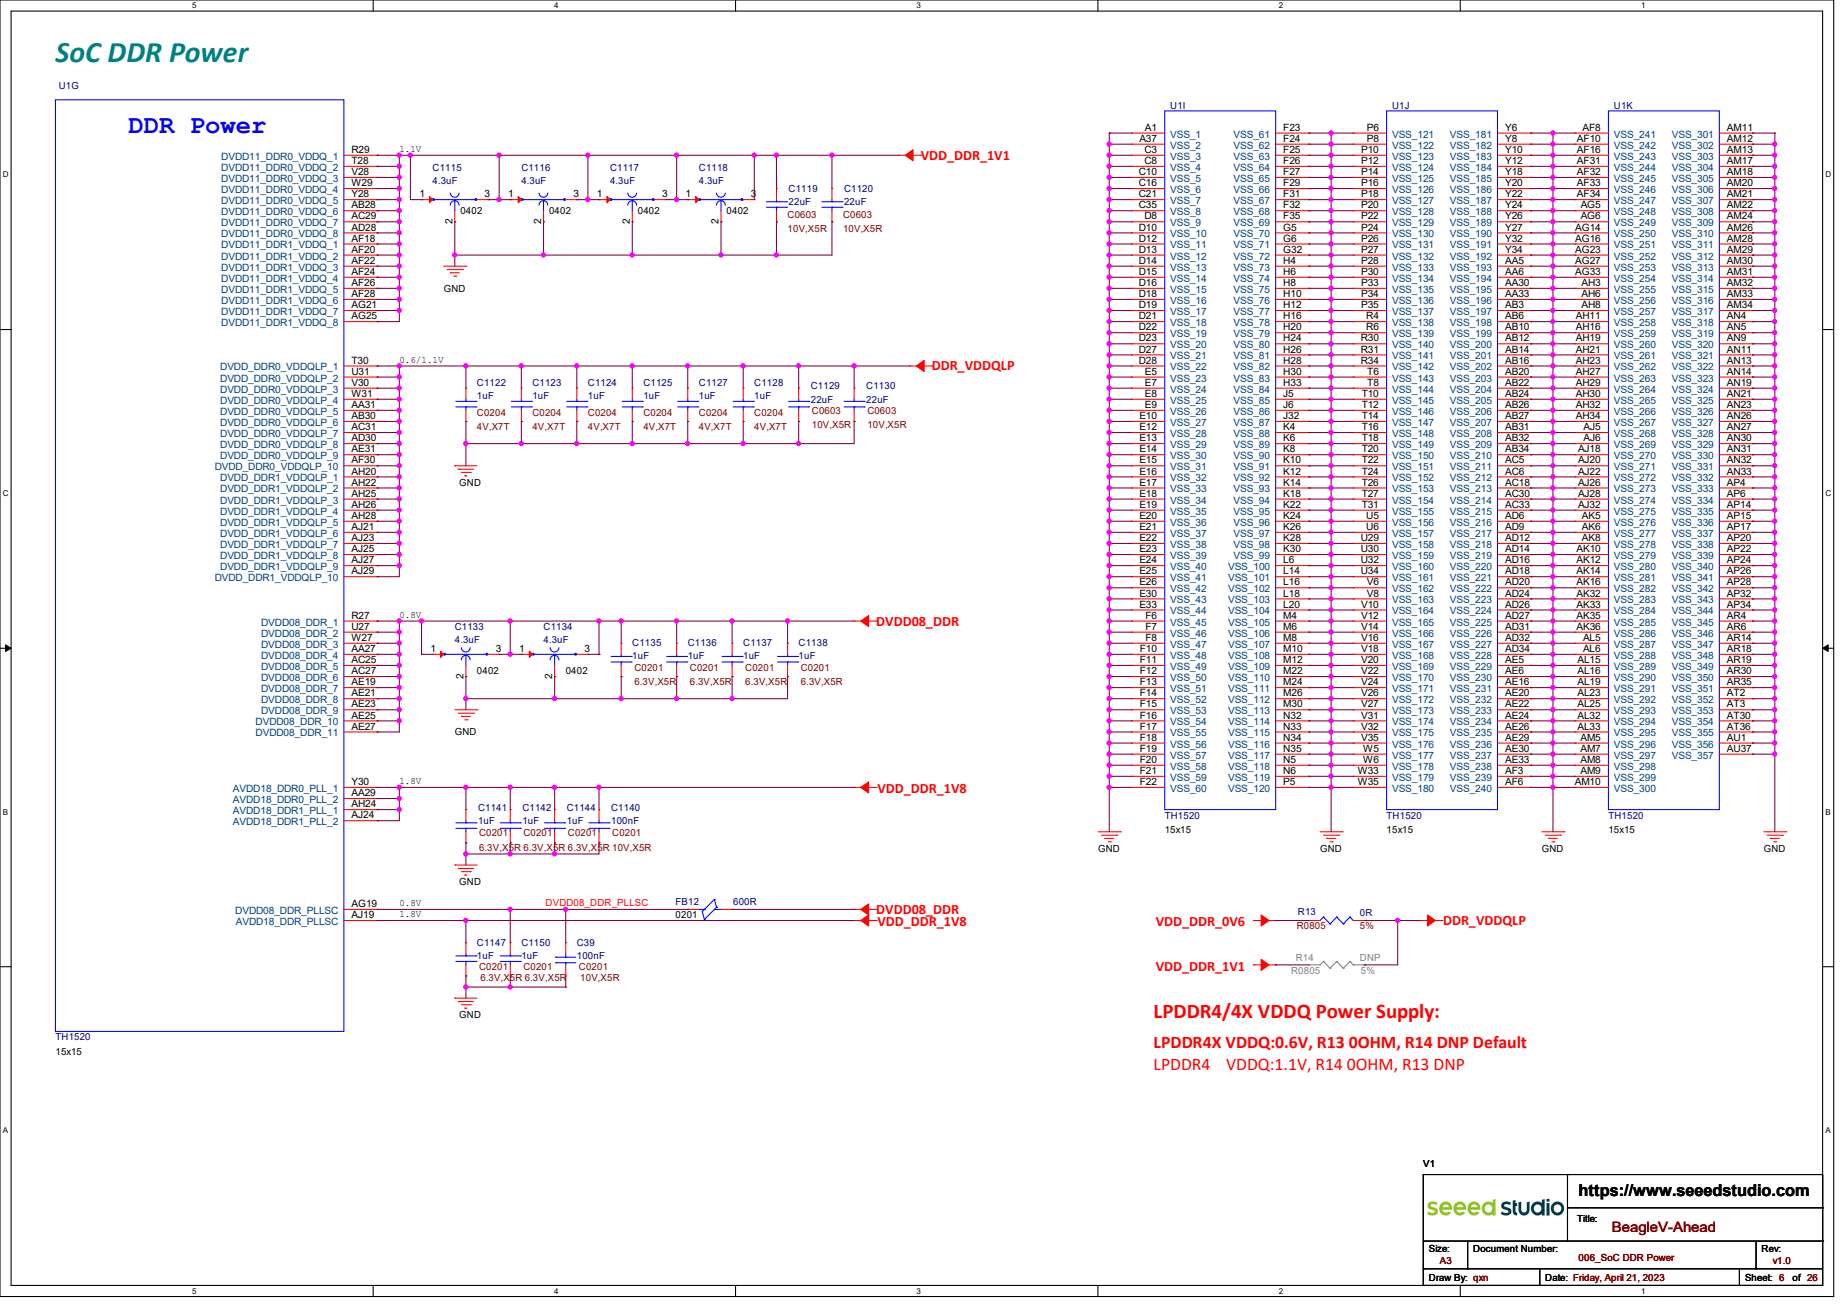
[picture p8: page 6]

GNDGND GND GND GND

# SoC DDR controller

## VDD_DDR_1V1

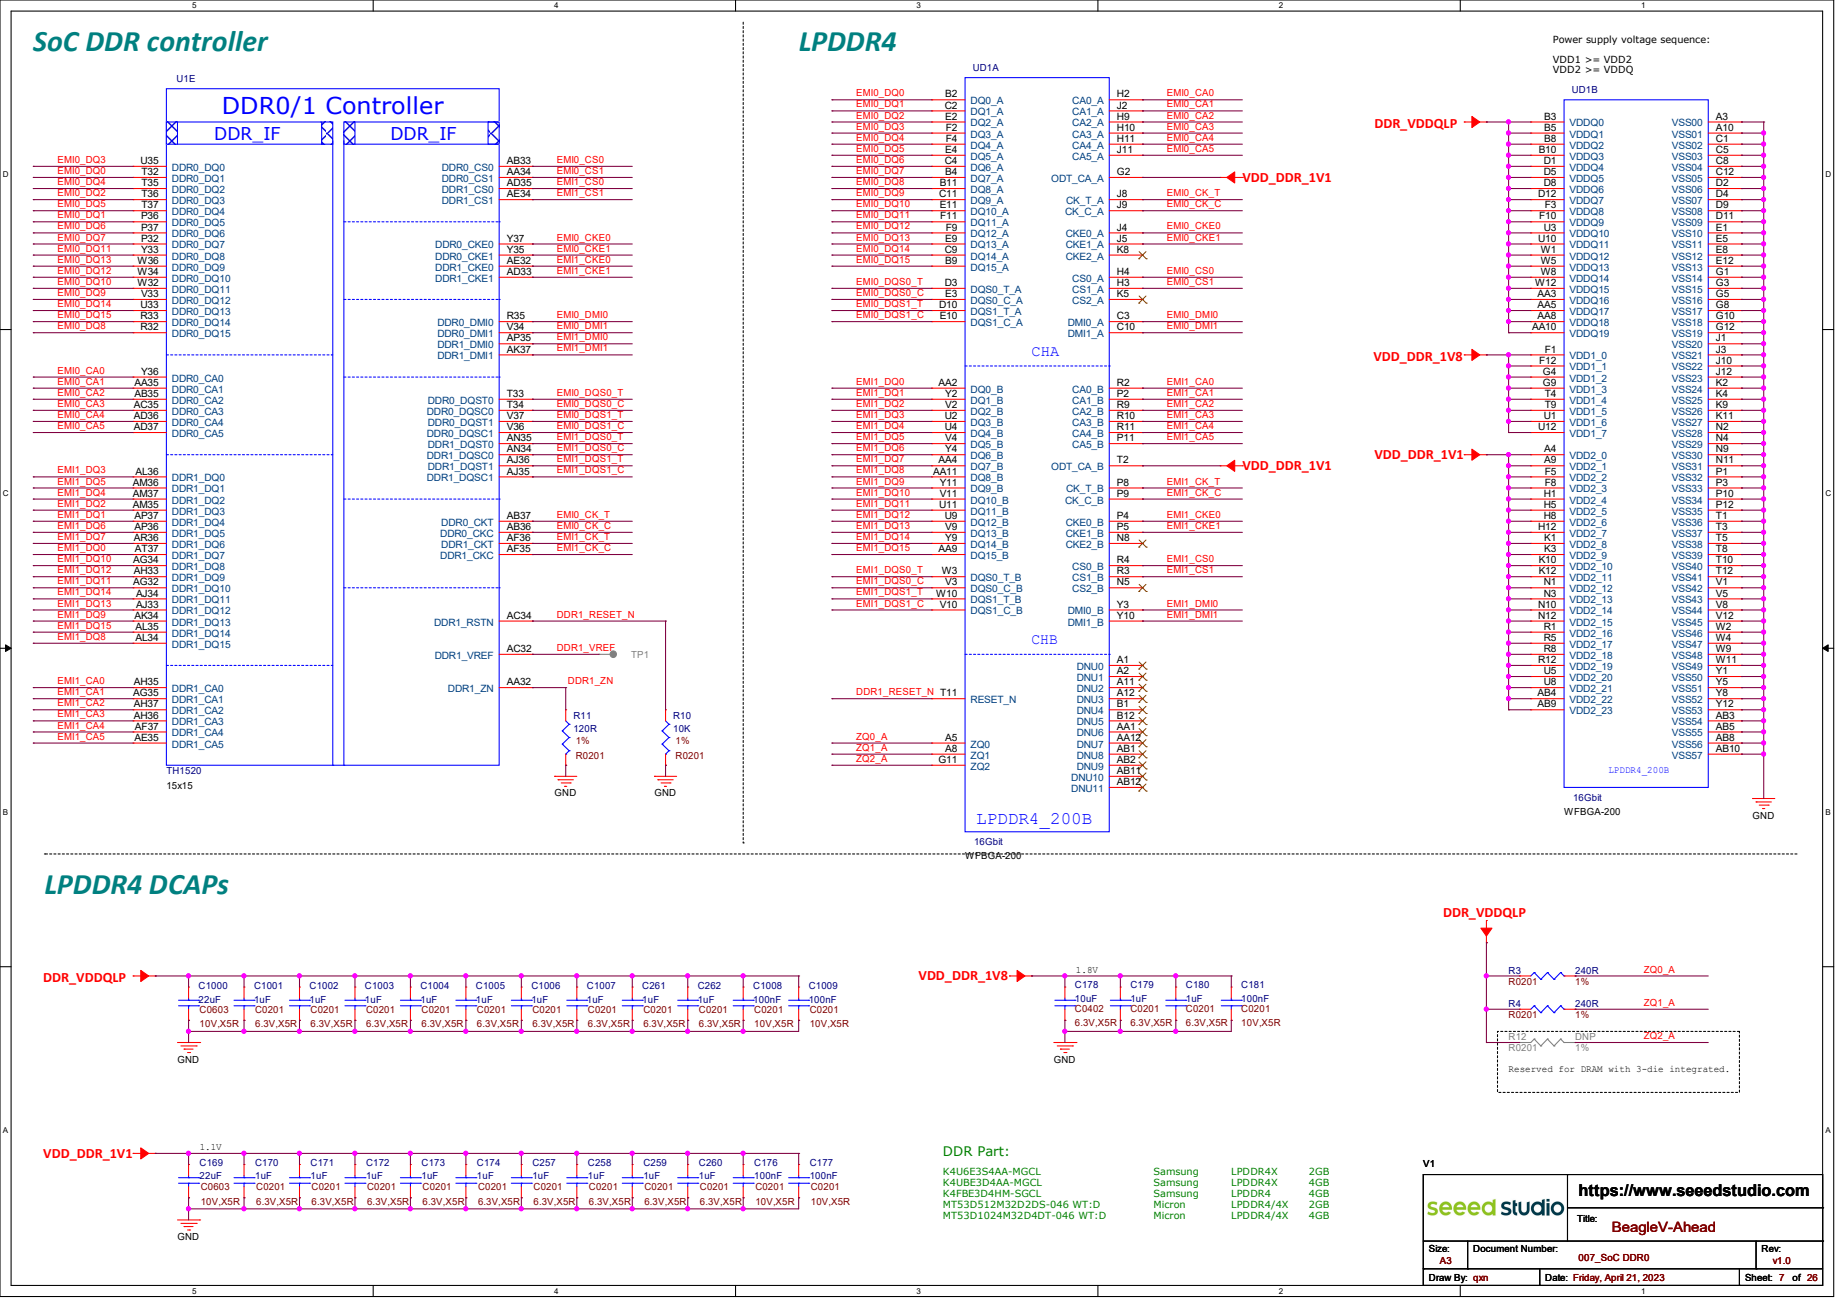
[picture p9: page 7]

Reserved for DRAM with 3-die integrated.

# SoC DDR controller

# LPDDR4

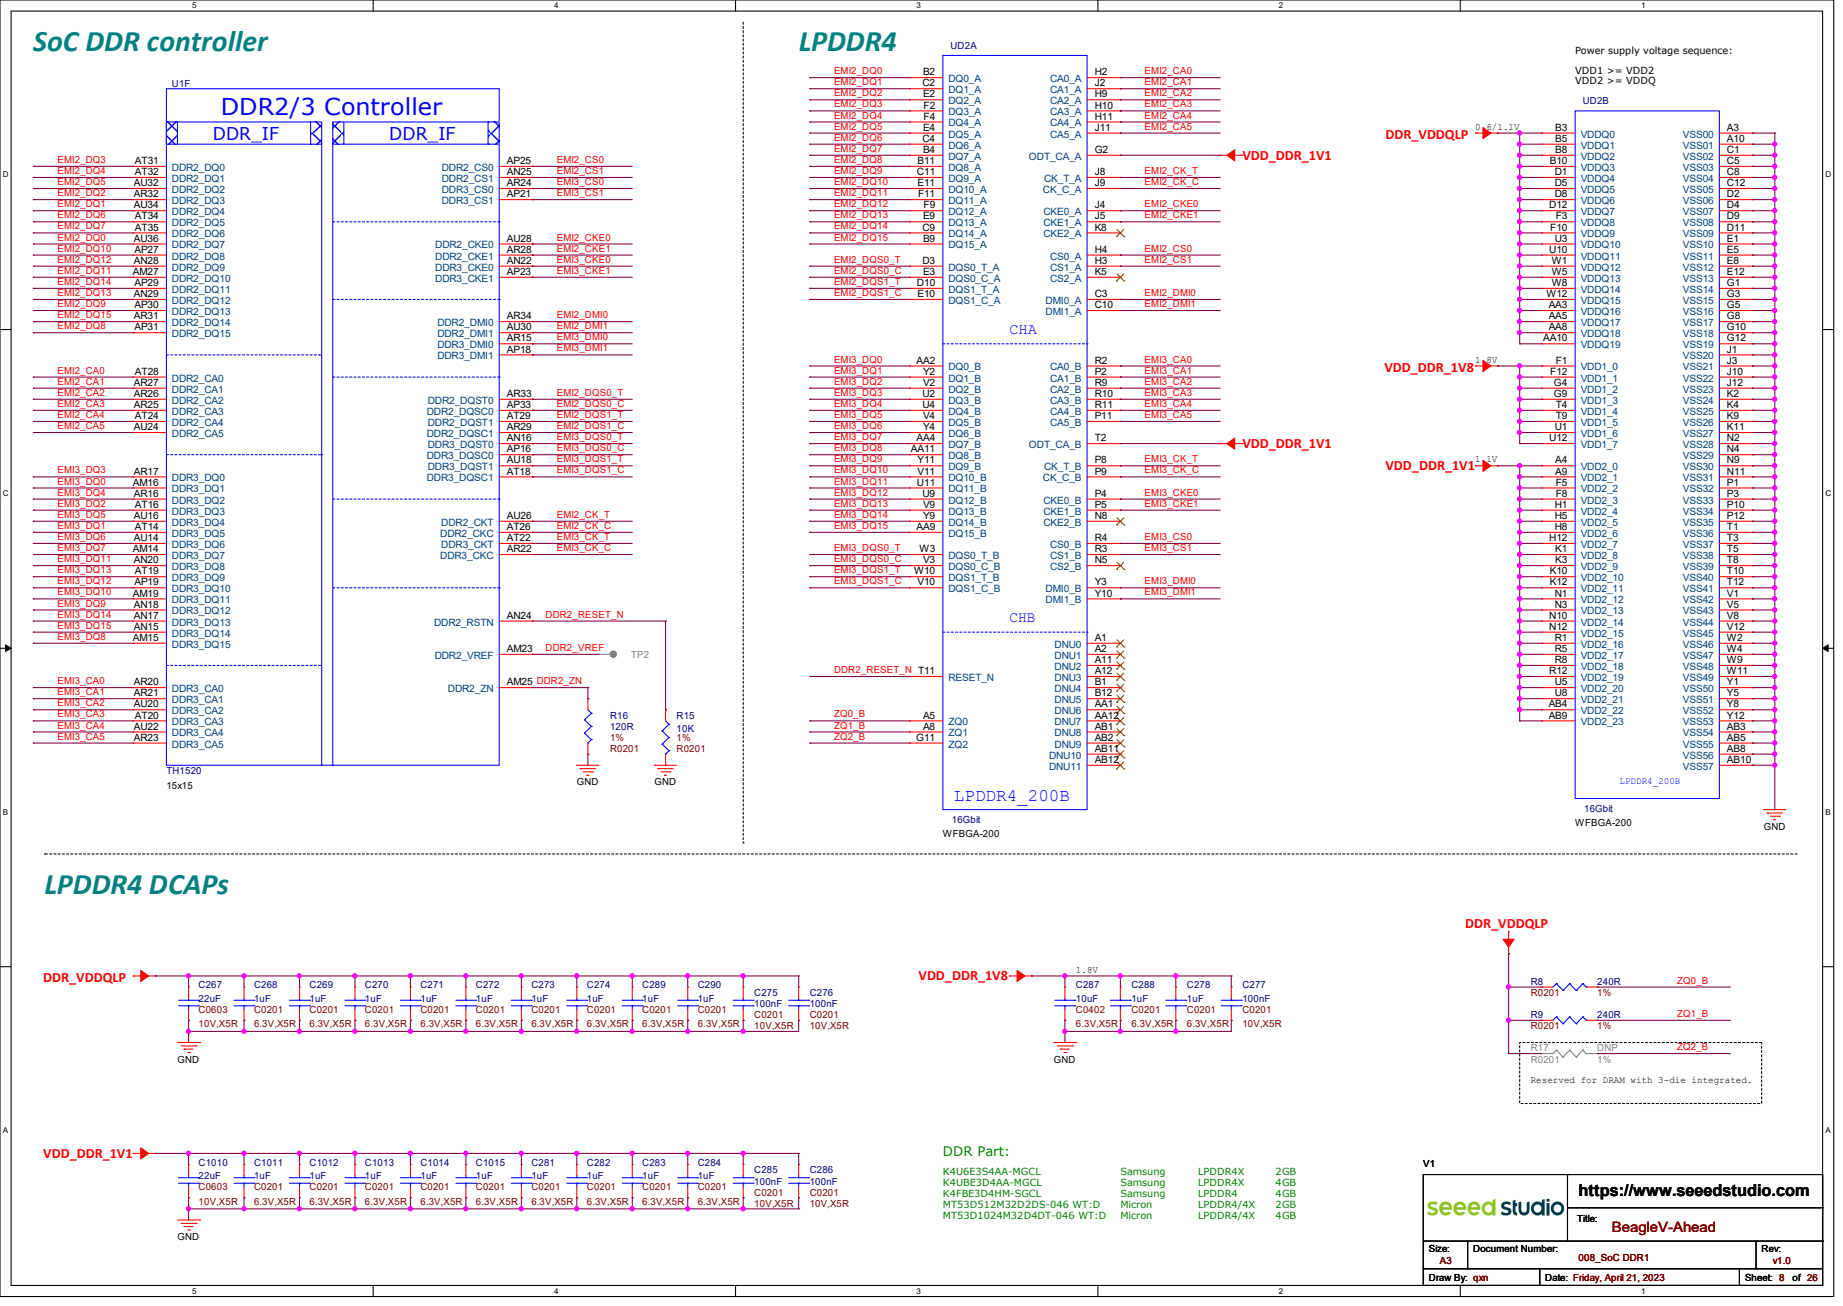
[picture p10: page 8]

Reserved for DRAM with 3-die integrated.

# SoC SDIO & eMMC & SD eMMC

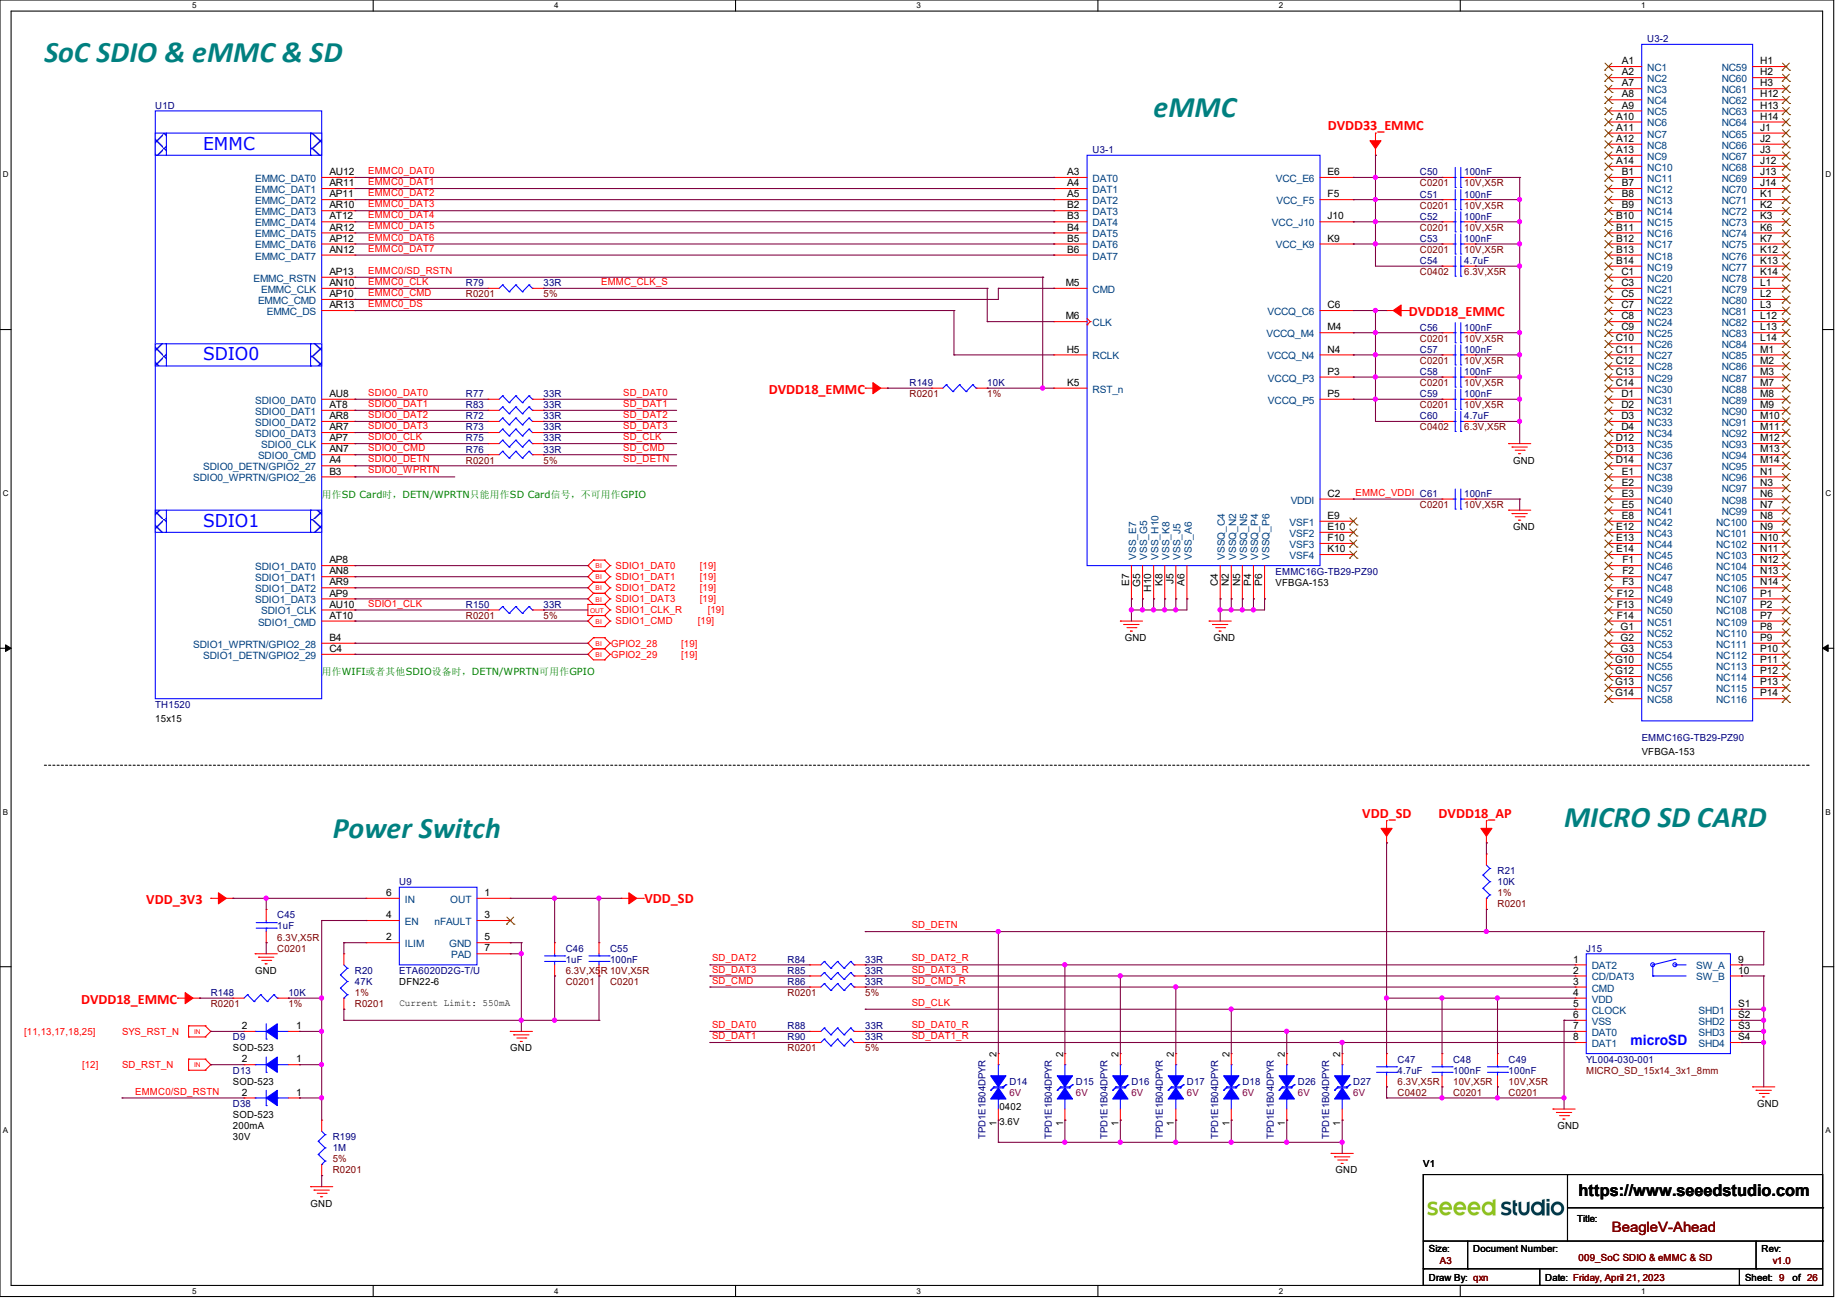
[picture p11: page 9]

用作SD Card时，DETN/WPRTN只能用作SD Card信号，不可用作GPIO

SoC MIPI CSI & DSI & HDMI GND | GND GND | GND GND
[21] | MIPI_CSI2_CLKN | IN [21] | MIPI_CSI2_CLKP | IN [21] | MIPI_CSI2_DATAN0 | IN [21] | MIPI_CSI2_DATAP0 | IN [21] | MIPI_CSI2_DATAN1 | IN [21] | MIPI_CSI2_DATAP1 | IN [21] | MIPI_CSI2_DATAN2 | IN [21] | MIPI_CSI2_DATAP2 | IN [21] | MIPI_CSI2_DATAN3 | IN [21] | MIPI_CSI2_DATAP3 | IN [21] | MIPI_CSI2X2_A_CLKN | IN [21] | MIPI_CSI2X2_A_CLKP | IN [21] | MIPI_CSI2X2_A_DATAN0 | IN [21] | MIPI_CSI2X2_A_DATAP0 | IN [21] | MIPI_CSI2X2_A_DATAN1 | IN [21] | MIPI_CSI2X2_A_DATAP1 | IN MIPI_CSI2X2_B_CLKN | IN MIPI_CSI2X2_B_CLKP | IN [21] | MIPI_CSI2X2_B_DATAN0 | IN [21] | MIPI_CSI2X2_B_DATAP0 | IN [21] | MIPI_CSI2X2_B_DATAN1 | IN [21] | MIPI_CSI2X2_B_DATAP1 | IN

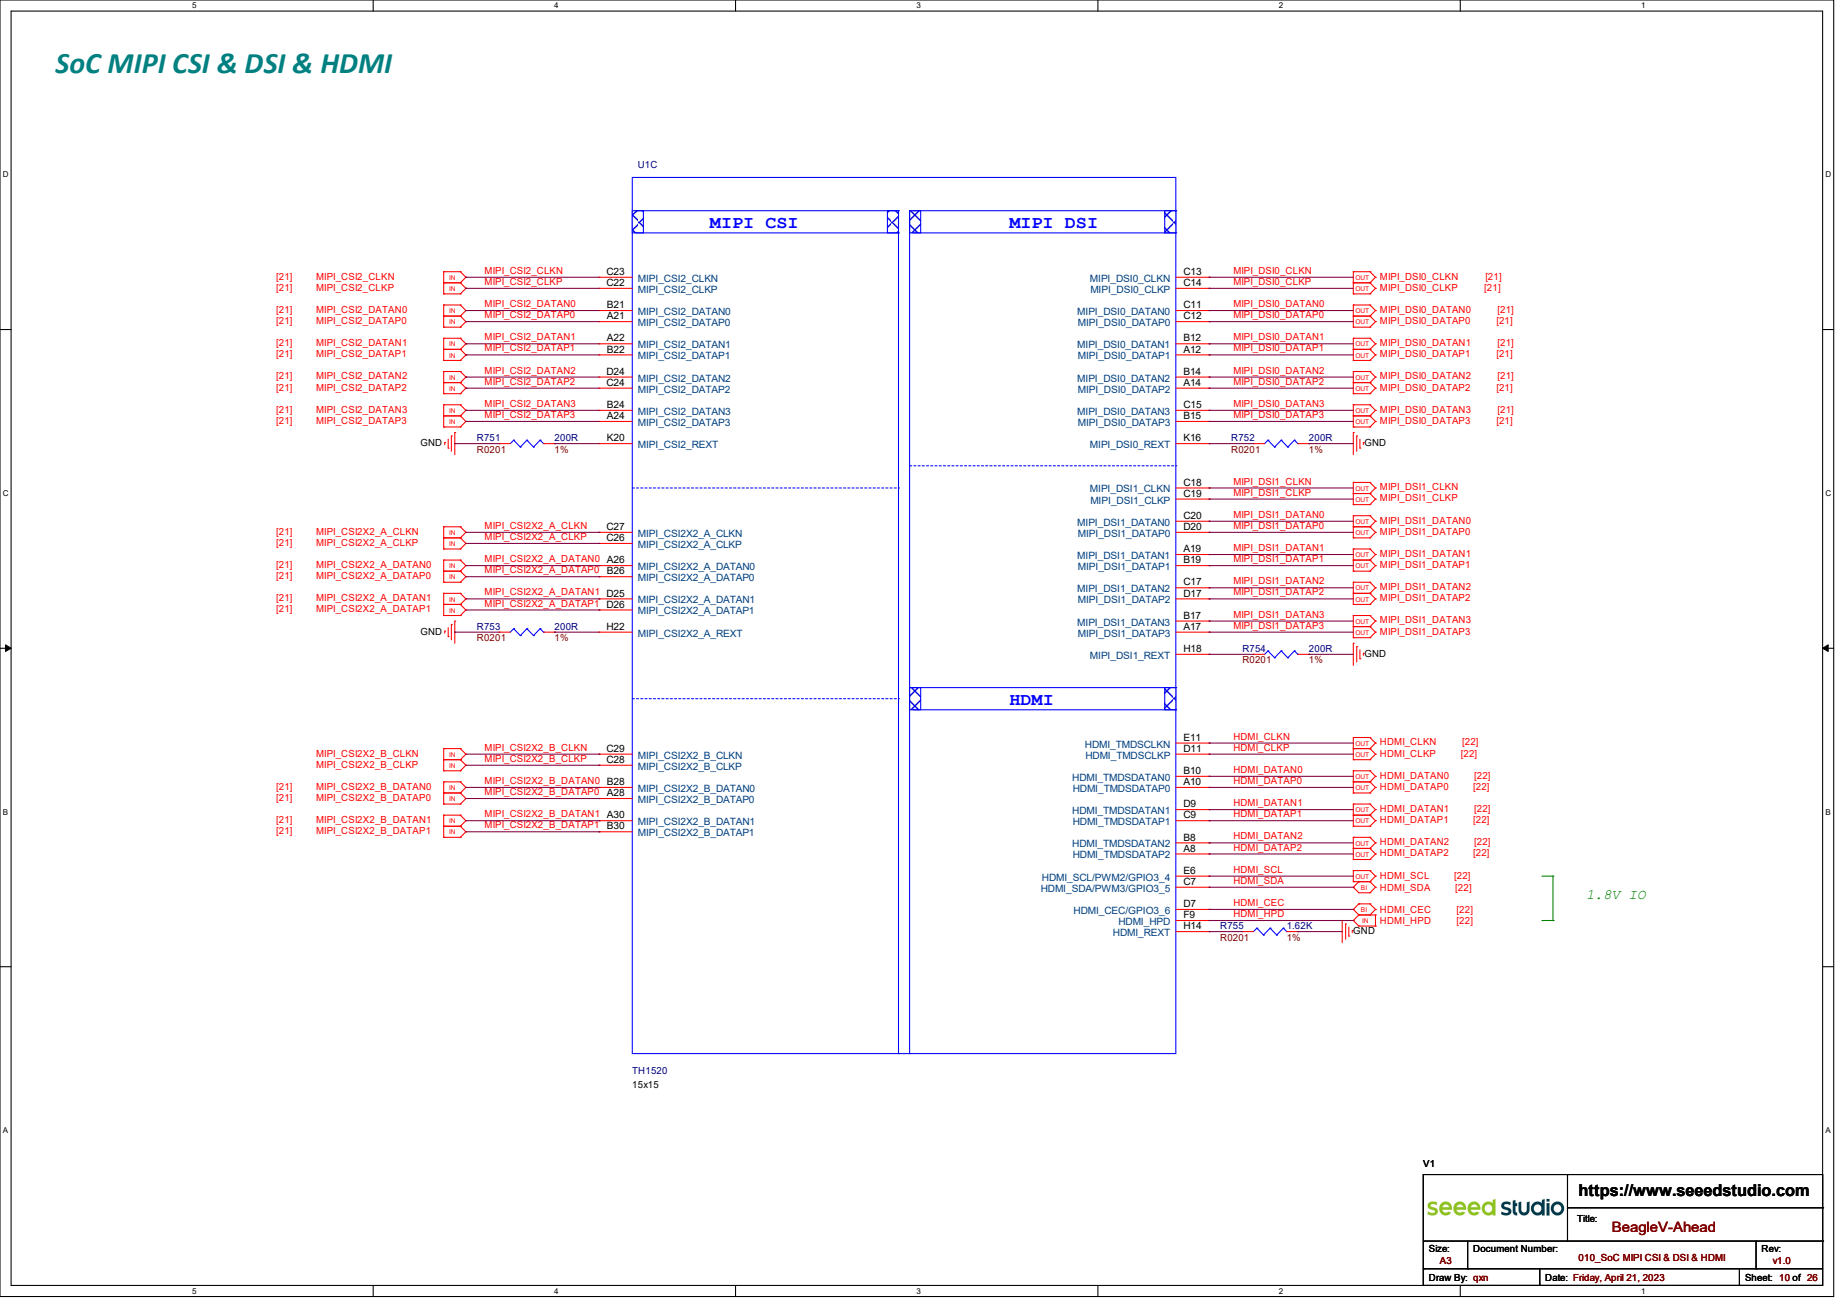
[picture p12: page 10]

010_SoC MIPI CSI & DSI & HDMI V1

SoC SYS & ADC & Clock ..

# IO PAD DSP0 JTAG

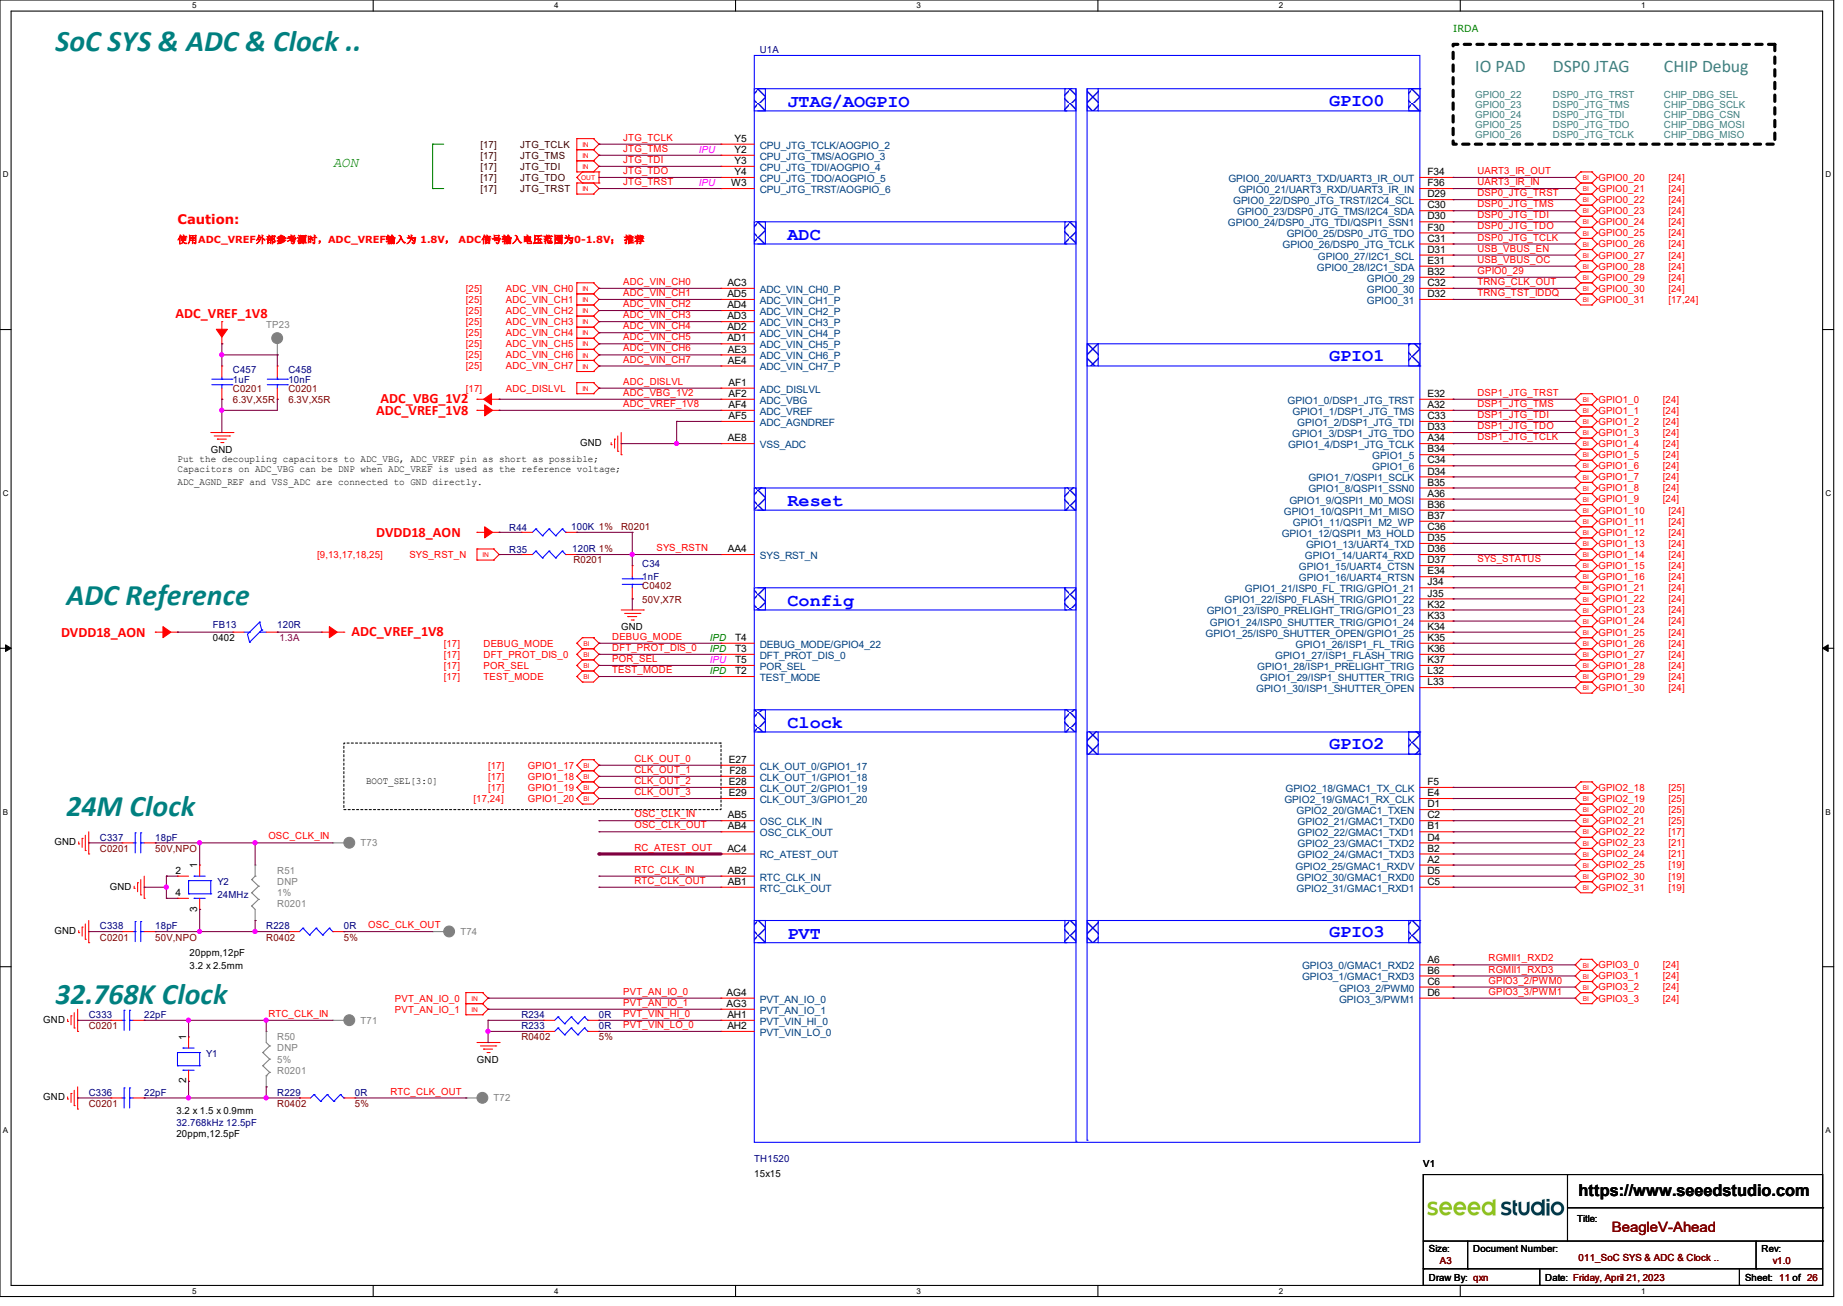
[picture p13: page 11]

IPU Put the decoupling capacitors to ADC_VBG, ADC_VREF pin as short as possible;

Capacitors on ADC_VBG can be DNP when ADC_VREF is used as the reference voltage;
ADC_AGND_REF and VSS_ADC are connected to GND directly.

SoC USB & GMAC & Audio ..

## AON

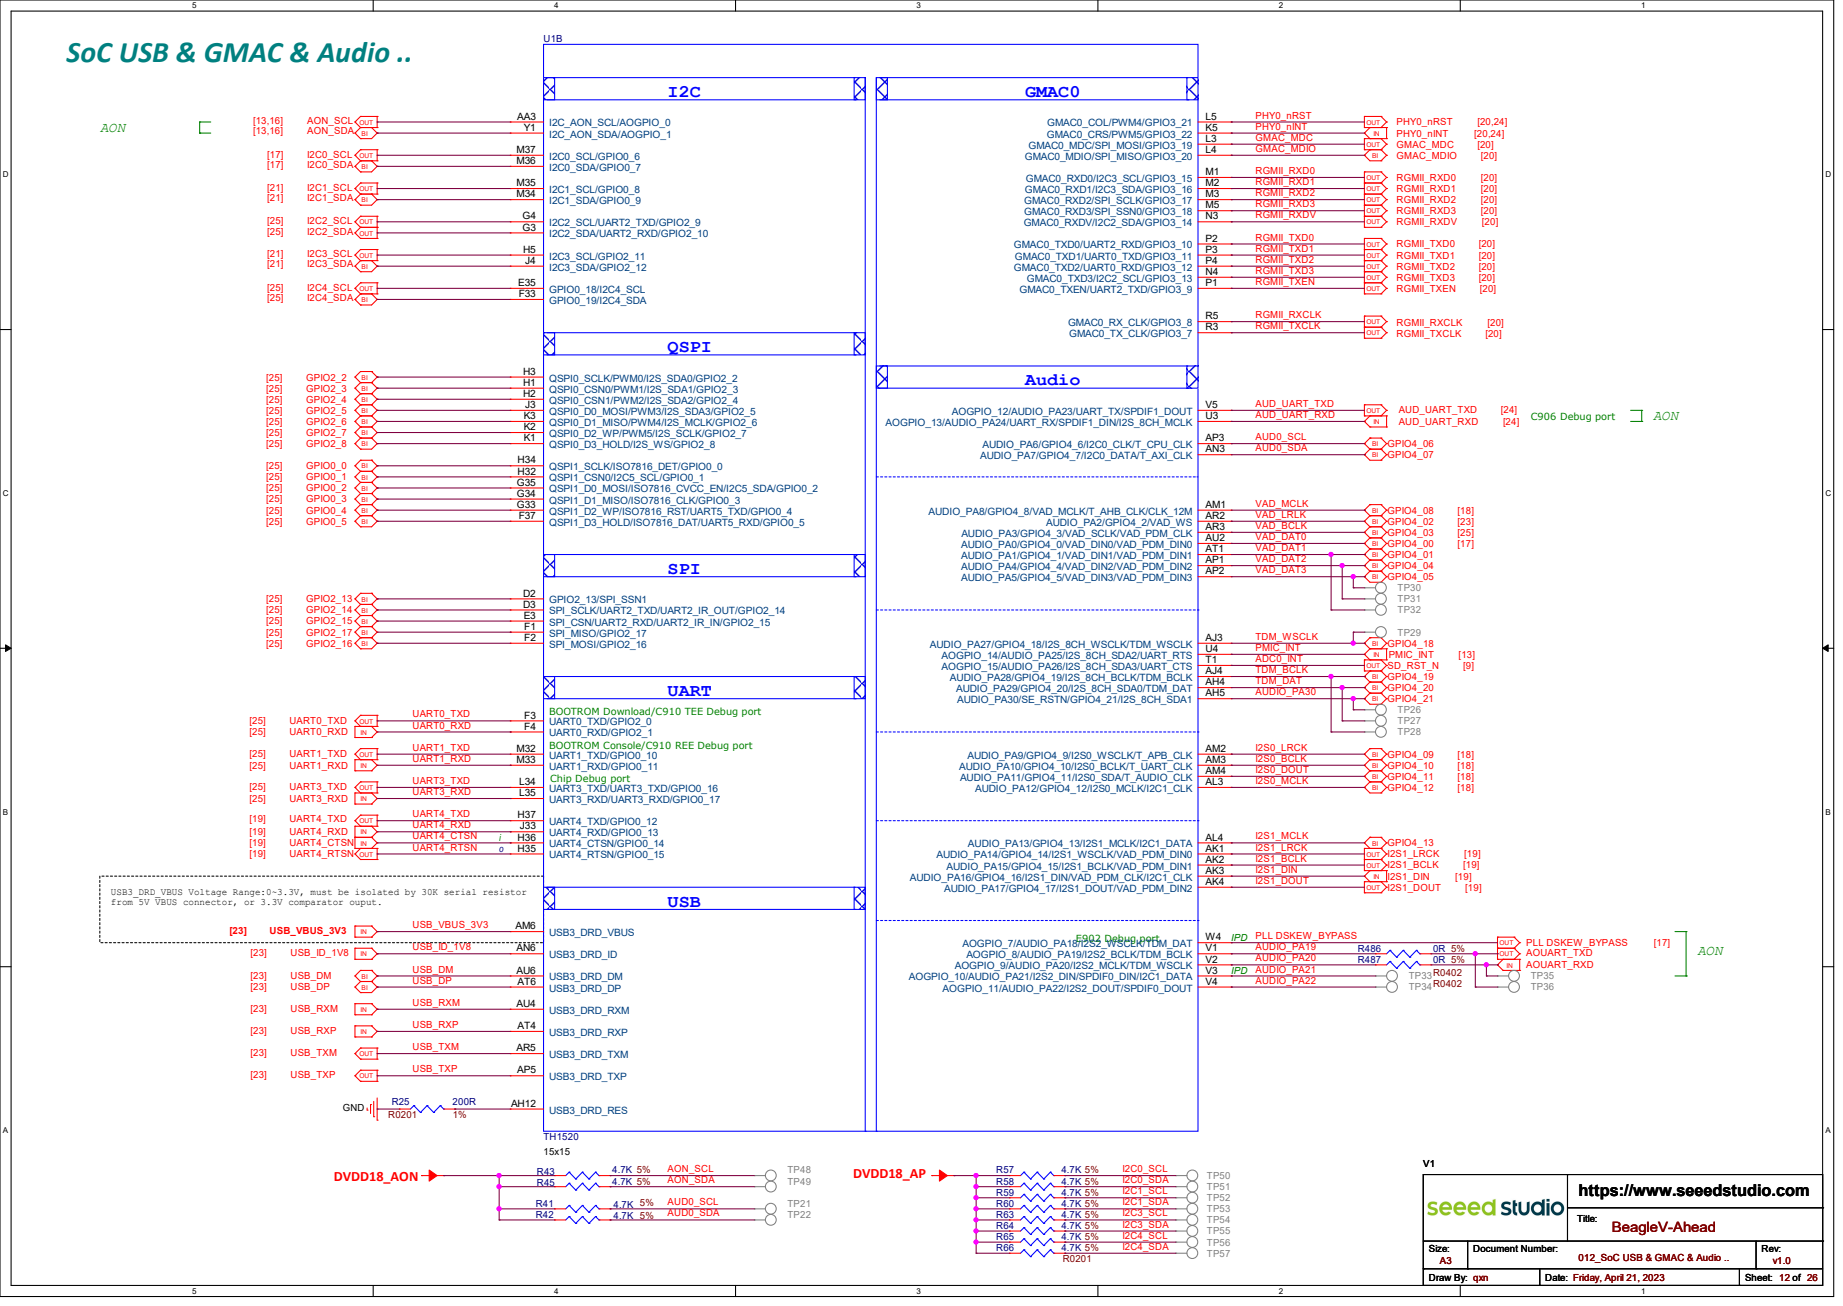
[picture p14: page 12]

BOOTROM Download/C910 TEE Debug port

BOOTROM Console/C910 REE Debug port

USB3_DRD_VBUS Voltage Range:0~3.3V, must be isolated by 30K serial resistor
from 5V VBUS connector, or 3.3V comparator ouput.

## OTP Setting

## OTP Setting

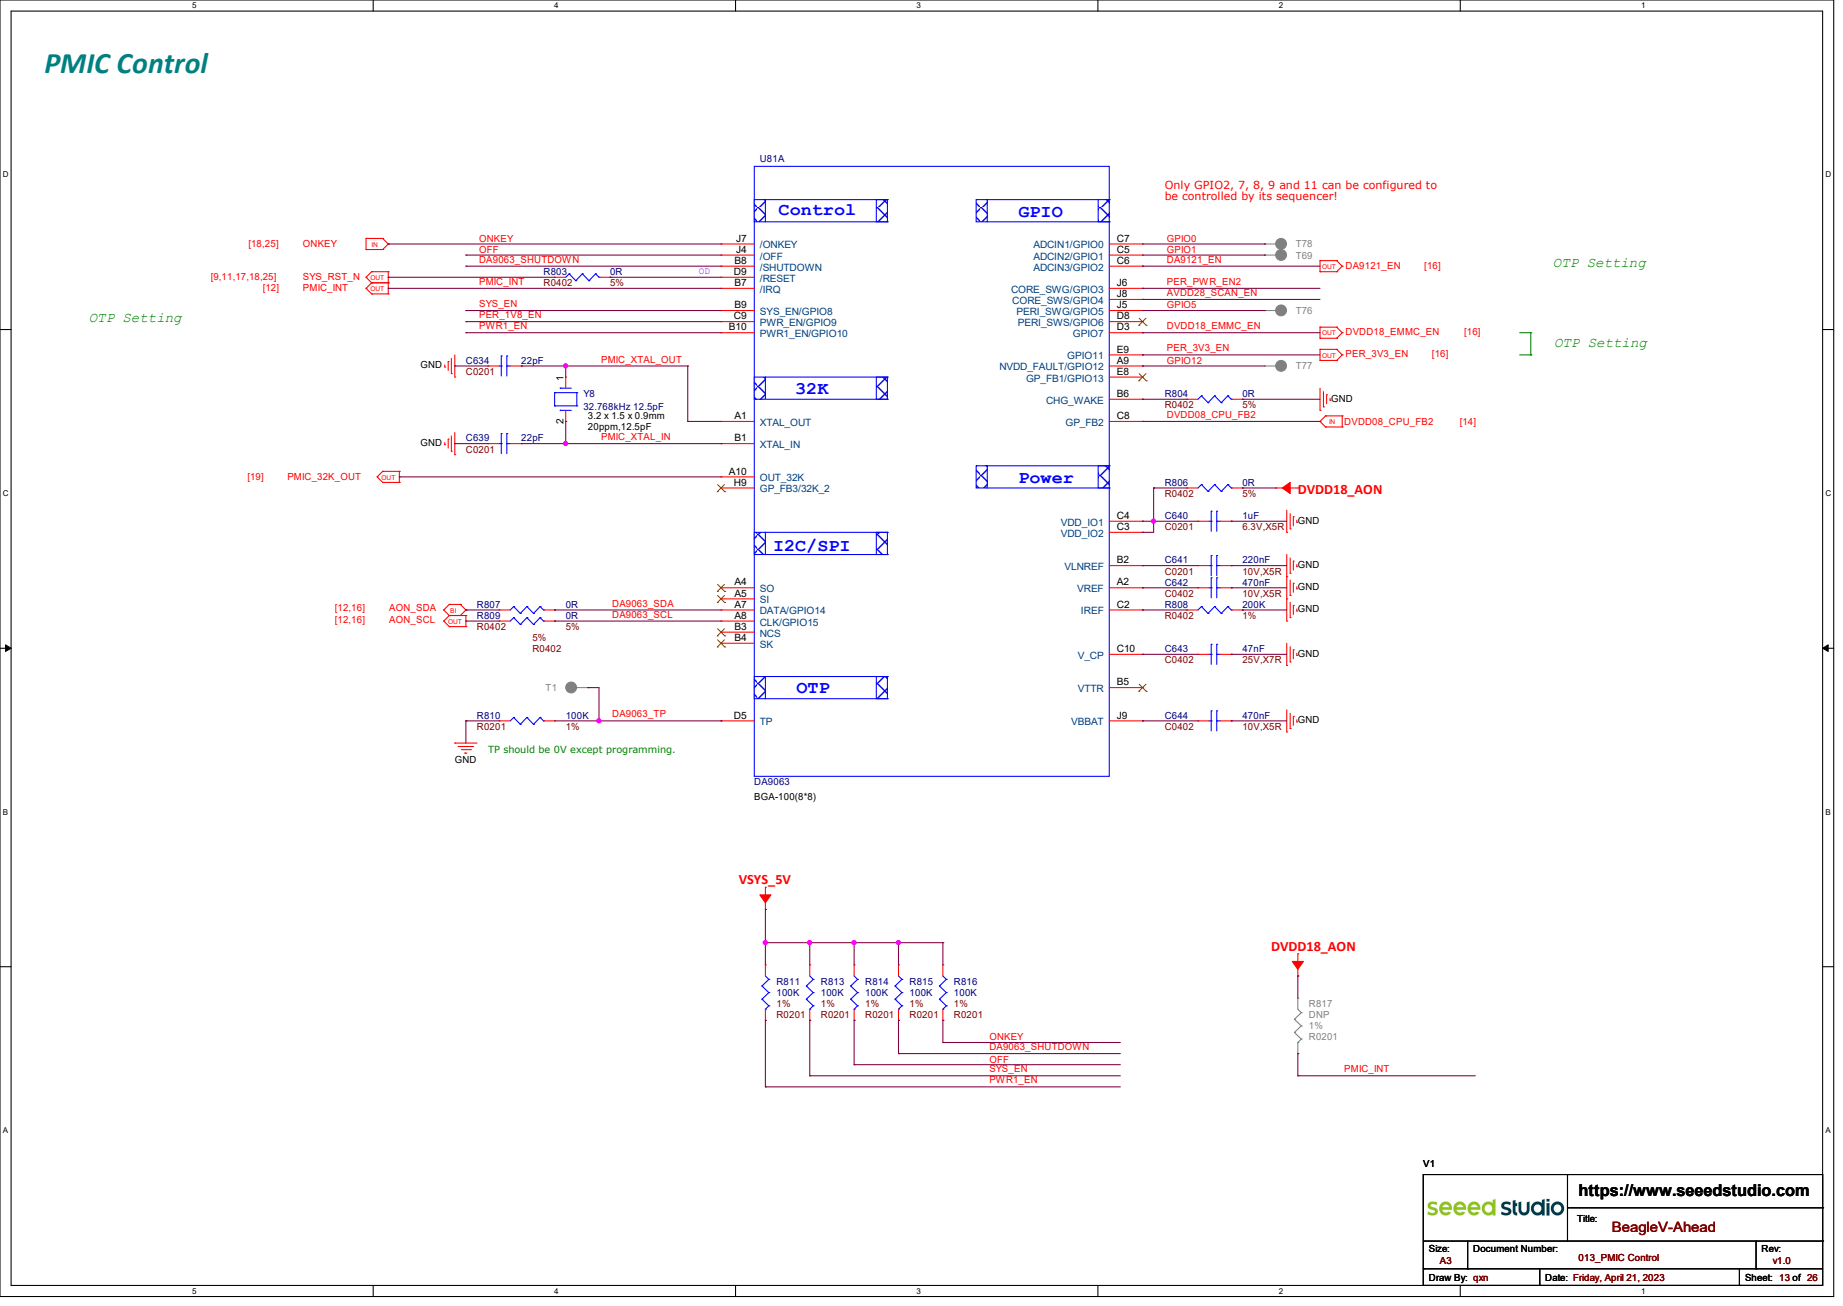
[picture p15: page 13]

Only GPIO2, 7, 8, 9 and 11 can be configured to

be controlled by its sequencer! OD

VBBAT J9 VDD_IO2 C3 VDD_IO1 C4 VREF A2 VLNREF B2 VTTR B5 V_CP C10

TP should be 0V except programming.

# PMIC Buck

## VBUCKCORE1


FB1P/N should be routed from CPU area. P connects to power, N connects to GND.

1.1V/1.5A Place capacitors close to each pad.

# PMIC LDO
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

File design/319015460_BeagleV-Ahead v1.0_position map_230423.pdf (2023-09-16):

# ART FILM - assy-top

D33


ART FILM - assy-top

# ART FILM - assy-bott

# C63R146 D35


ART FILM - assy-bott

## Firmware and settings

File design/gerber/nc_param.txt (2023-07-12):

INTEGER-PLACES         2
DECIMAL-PLACES         5
X-OFFSET               0.000000
Y-OFFSET               0.000000
FEEDRATE               1
COORDINATES            ABSOLUTE
OUTPUT-UNITS           ENGLISH
TOOL-ORDER             INCREASING
REPEAT-CODES           YES
SUPPRESS-LEAD-ZEROES   NO
SUPPRESS-TRAIL-ZEROES  NO
SUPPRESS-EQUAL         NO
TOOL-SELECT            YES
OPTIMIZE_DRILLING      NO
ENHANCED_EXCELLON      YES
HEADER                 none
LEADER                 12
CODE                   ASCII
SEPARATE               NO
SEPARATE-ROUTING       NO
DRILLING               LAYER-PAIR
BACKDRILL              NO
CAVITY                 NO
COUNTER                NO
TOLERANCE_DRILL        NO
TOLERANCE_TRAVEL       NO
TOOL_SIZE              NO
ROTATION               NO
NON_STANDARD           NO
TOTAL_DRILL            NO
SEPARATE_SLOT          NO
SUPPRESS_TOLERANCE     NO
SUPPRESS_TOOLSIZE      NO
SUPPRESS_ROTATION      NO

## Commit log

2023-07-12 Add V1.0 design
    [BEAGLEV-AHEAD V11_no_logo-1-10.drl, BEAGLEV-AHEAD V11_no_logo-1-2.drl, BEAGLEV-AHEAD V11_no_logo-1-3.drl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]
2023-09-16 Add v1.0 design files
    [202003615_PCBA_BeagleVAhead_A11_Design-BOM.csv, 319015460_BeagleV-Ahead v1.0_location_230423.xlsx]
2023-09-28 Remove version from schematic PDF filename.
